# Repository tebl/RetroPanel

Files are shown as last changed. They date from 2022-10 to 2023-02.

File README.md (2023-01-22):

# RetroPanel
Having found a motherboard I really wanted to use, I found that obtaining an AT-case wasn't quite as easy as I had expected - at least none that met my demands for condition, price and availability anywhere near me. That's the short of it, see [Background](#2-background) for the full story. Anyway, my solution to my predicament was to simply use a slightly more modern ATX-case, but I wanted it to have all of the features available to even the earlies of computer generations available to me - that includes a working power switch, a turbo-switch and one of those awesome looking Mhz-displays. Add a clock and a temperature-sensor and it soon becomes apparent: such a thing, only had the potential to exist in my head.

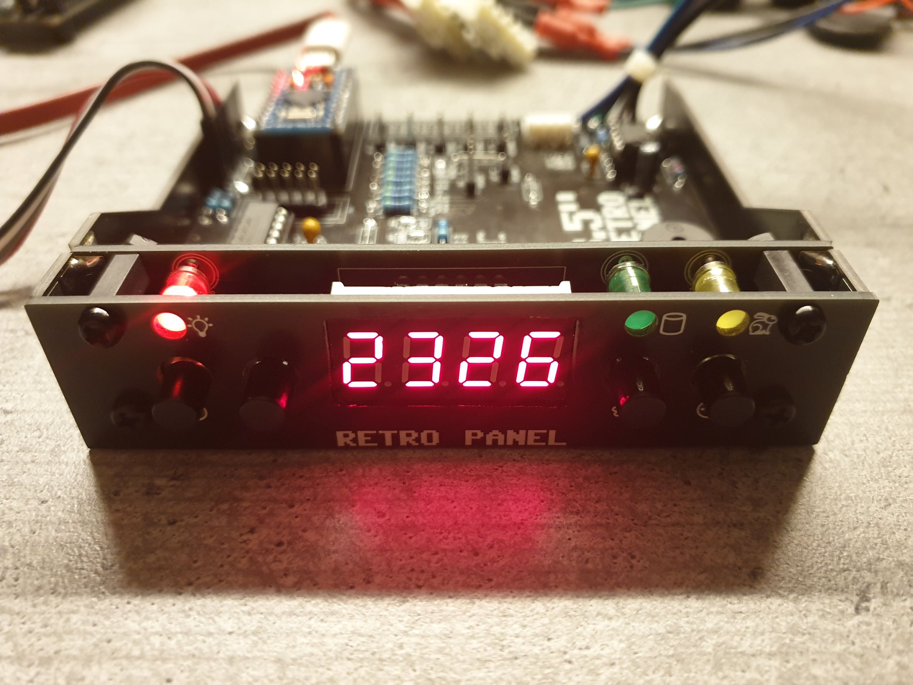
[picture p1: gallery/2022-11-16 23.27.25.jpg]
RetroPanel

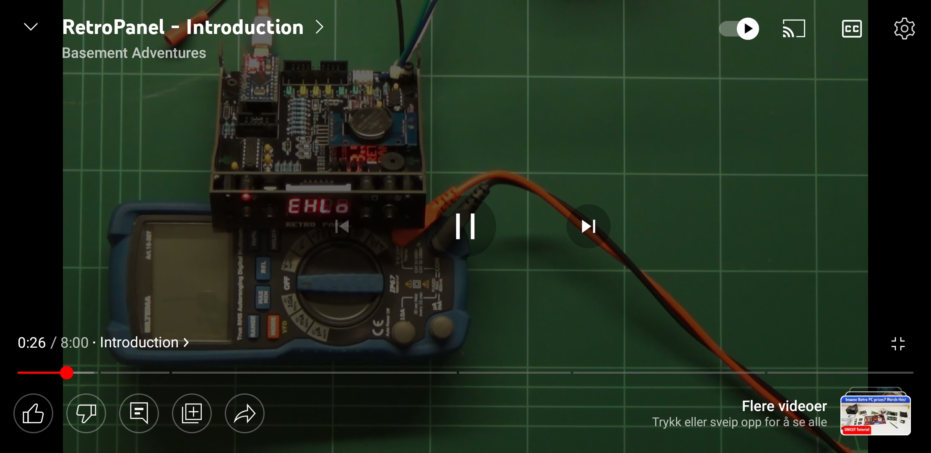
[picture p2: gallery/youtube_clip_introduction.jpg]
YouTube image (https://youtu.be/AMw6y9zLjqE)


So I made one.

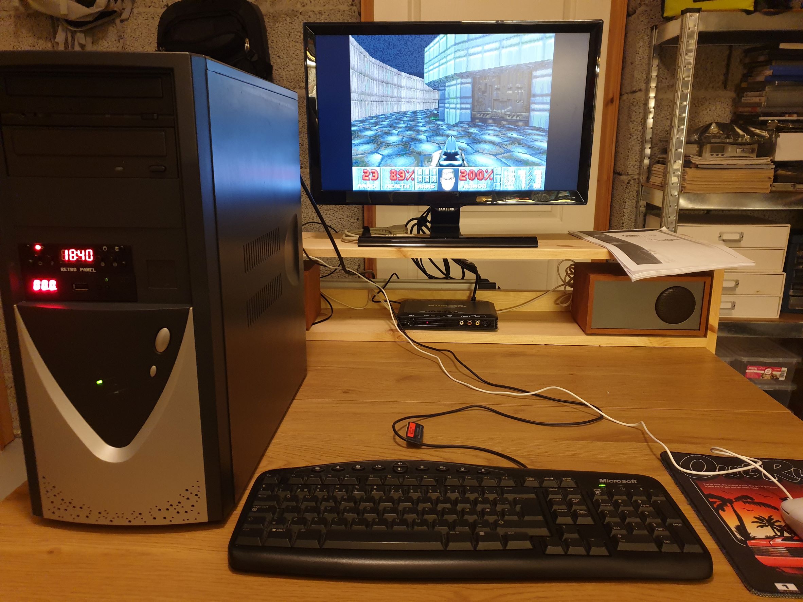
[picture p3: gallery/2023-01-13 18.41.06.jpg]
In action


The resulting computer isn't what I had originally intended to build, but I am quite happy with the results. There are better MBs, there are faster CPU options available and the graphics card will excite no other retro enthusiast other the one I grew into - however, it is exactly the *"right"* kind of slow for the games I remember. The *RetroPanel* was the missing piece to make all of that work, and with the wonders of *open-source* you should now have everything you need to build one as well.

- [1> Versions](#1-versions)
  - [1.1> RetroPanel](#11-retropanel)
- [2> Background](#2-background)
- [3> Resources](#3-resources)
- [4> Acknowledgements](#4-acknowledgements)

# 1> Versions
While there may only be one version of the RetroPanel for quite some time, but knowing myself and the fact that it has become a form factor that I really like - in time there will be more than one version of the RetroPanel. The differences will more than likely be in core functionality, not in terms of different faceplates that should already be catered for in the standard version.

| Module | Description |
| --- | --- |
| [RetroPanel](#11-retropanel) | Standard version

## 1.1> RetroPanel
RetroPanel

The standard version of the RetroPanel, envisioned to provide most features found on cases from even the earlies of computer generations - that includes a working power switch, a turbo-switch and one of those awesome looking Mhz-displays. With options for installing modules for adding a clock (RTC) to it as well as a temperature-sensor (BMP280).

The standard version is composed of the following set of PCBs, in the cases of alternative faceplates you would only need the one that is suitable for your needs. Follow the documentation links for specific information related to each of them, note that the documentation on building one of these units this is covered through the documentation for the main PCB ([RetroPanel Module](https://github.com/tebl/BulkyMIDI-32/tree/main/BulkyMIDI-32%20Module)).

| PCB | # Required | Description | Documentation | Order |
| --- | --- | --- | --- | --- |
| [RetroPanel Module](https://github.com/tebl/RetroPanel/tree/main/RetroPanel%20Module) | 1 | Main module | [Documentation](https://github.com/tebl/RetroPanel/blob/main/RetroPanel%20Module/README.md), [BOM](https://github.com/tebl/RetroPanel/blob/main/RetroPanel%20Module/README.md#3-bom) | PCBWay
| [RetroPanel Front](https://github.com/tebl/RetroPanel/tree/main/RetroPanel%20Front) | 1 | Front-facing board holding components | [Documentation](https://github.com/tebl/RetroPanel/blob/main/RetroPanel%20Front/README.md), [BOM](https://github.com/tebl/RetroPanel/blob/main/RetroPanel%20Front/README.md#3-bom) | PCBWay
| [RetroPanel Side](https://github.com/tebl/RetroPanel/tree/main/RetroPanel%20Side) | 2 | Design for the sides, you need two of these. | [Documentation](https://github.com/tebl/RetroPanel/blob/main/RetroPanel%20Side/README.md) | PCBWay
| [RetroPanel Faceplate (FP1)](https://github.com/tebl/RetroPanel/tree/main/faceplates/RetroPanel%20FP1) | 1 | Faceplate that goes on the very front of the module, this has provisions for all switches and LEDs | [Documentation](https://github.com/tebl/RetroPanel/tree/main/faceplates/RetroPanel%20FP1) | PCBWay

# 2> Background
Recently I had the glorious idea of rebuilding the first PC I bought, it was a low-budget option put together from a list of parts in the later parts of 1995. Due to sheer luck I still had some driver disks that came with it, so I knew that what I was looking for was a motherboard with the model number *P51437P4/FMB* as well as a *Cirrus Logic 5436* graphics card. Surprisingly expensive, no doubt because noone had felt like keeping the super-cheap hardware options in the first place - additionally it was an AT-motherboard with one of those clocks that you couldn't exchange the battery for.

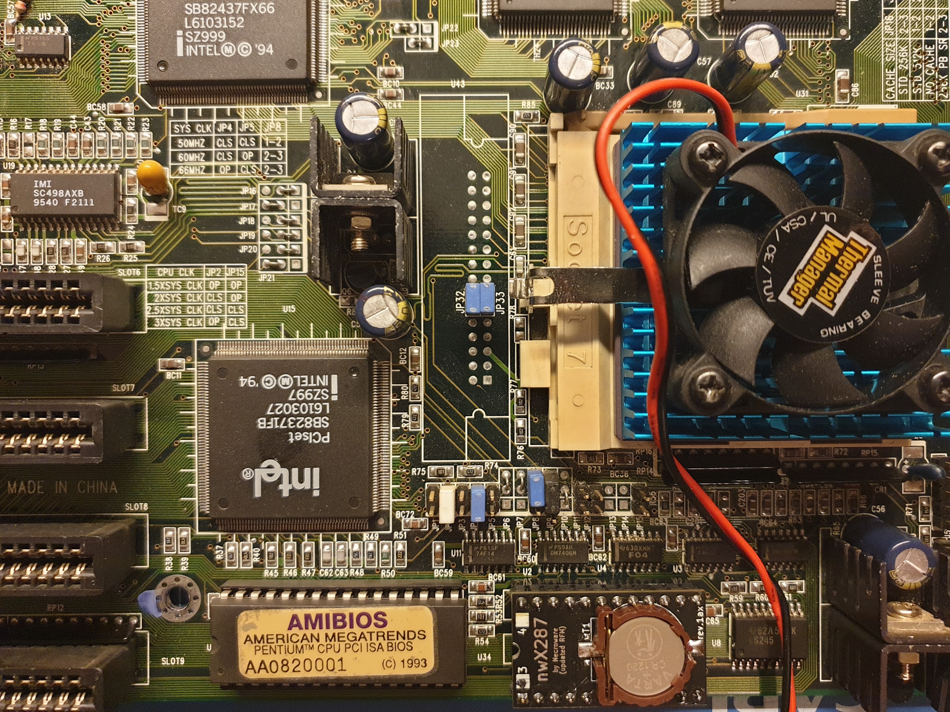
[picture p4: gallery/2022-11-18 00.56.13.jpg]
Old motherboard


Why does that matter? It doesn't, but the next thing does: I couldn't find an AT-case that wasn't either horribly mangled, situated around a collectors more beloved hardware or any combination of the two. Well, that's not completely true - I found and bought a case, but it was thrown from every moving postal truck from Poland all the way up to where I live - bringing us back to the first point on my little list.

RetroPanel in new case

No doubt having already listened in on my internal dialogue, YouTube gave me a viewing recommendation for a video from [philscomputerlab](https://www.youtube.com/@philscomputerlab) - [Building the 486 DX2 66 Retro Sleeper DOS PC](https://youtu.be/9bqqpuJ7M_I). What I liked with it was that he gave me a viable option by gently reminding me that ATX-cases are still plentiful, they're even easier to match the aesthetics of as most of the little bits are still being sold. His solution for powering was to use an ATX to AT-cable and using a simple toggle switch as a power switch, as is the common way of doing it.

There's just one thing I don't like about that, is that a part of the designs of the ATX PSUs is telling the power-on circuit on your motherboard not to instantly turn it on again once a short has been detected on one of its power rails. Have you tried shorting a 35A power supply? It'll scare the crap out of you, possibly vaporizing something in the process. Add a latching switch and it may keep cycling until you remove the power lead.

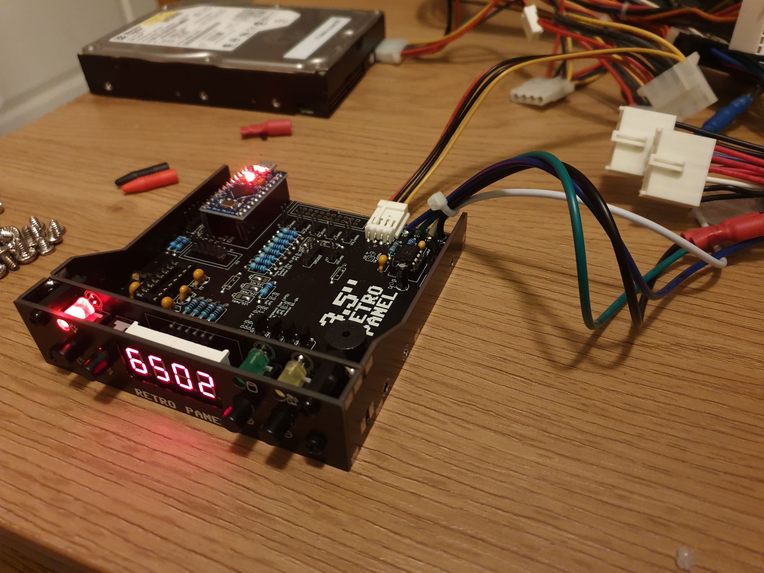
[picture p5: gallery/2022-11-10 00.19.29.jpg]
RetroPanel with PSU


I'm not saying that the RetroPanel in any way can be considered a safety precaution, because it haven't been tested enough to give you any other guarantee other than it having worked the one time I tried it. I still wouldn't keep a vintage computer powered without being in the room with it, but it gives me the peace of mind needed to turn my back long enough to fiddle with things such as this documentation.

# 3> Resources
The following resources where used as references when creating the RetroPanel, while they are in no particular order - you may find all of them interesting when looking for more information beyond what have been provided as part of this [GitHub-repository](https://github.com/tebl/RetroPanel). 

- [AT Power Pinout](http://www.hilmanind.com/pinouts/atpwr.htm)
- [ATX Power Pinout](https://www.etechnog.com/2022/03/atx-power-supply-pinout-diagram.html)
- [ATX Momentary Switch](https://www.instructables.com/Latching-Momentary-Switch-for-ATX-PSU-Conversion/)
- [PC power supply cables and connectors](http://www.playtool.com/pages/psuconnectors/connectors.html)
- [DIY POST Card](https://bbright.tripod.com/information/postcard.htm)
- [More POST Card information](https://www.minuszerodegrees.net/misc/post_cards.htm)

# 4> Acknowledgements
Everything comes from something, in particular when it comes to most of my electronics projects. I mainly build things I would like to own, often doing a respin to fit my own particular style and preferences. In many cases the hardest parts of the designs will already have been provided by people far more knowledgable than I. In particular the smart switch circuit, was adapted from [ATX Momentary Switch](https://www.instructables.com/Latching-Momentary-Switch-for-ATX-PSU-Conversion/).

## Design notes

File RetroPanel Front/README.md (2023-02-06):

# RetroPanel Front
This is a front-facing panel for controlling the *RetroPanel*, it holds all of the LEDs, switches as well as the 7-segment display associated with the RetroPanel itself. It mounts on the [RetroPanel Module](https://github.com/tebl/RetroPanel/tree/main/RetroPanel%20Module) using right-angle pin headers with slots cut into the PCBs to offer it some mechanical strength. The instructions for assembling one is mostly organized along with the main module, but the [BOM](#3-bom) included at the bottom of this document should be taken into account when ordering parts.

- [1> Building the device](#1-building-the-device)
  - [1.1> Soldering it together](#11-soldering-it-together)
- [2> Schematic](#2-schematic)
- [3> BOM](#3-bom)

# 1> Building the device
Building a device such as this assumes you have at least minor experience soldering things together, recommended is that you at the very least have access to a soldering station with adjustable temperature. If currently available, you should probably start with 60/40 rosin core solder as the lead-free alternatives tends to be a bit harder to work with.

With requirements for basic equipment sorted, we need to talk a bit about what you want to achieve while building this project. The reason I ask is that while you can build a *RetroPanel* with every feature available, it may not make sense for the computer it's going into. What I mean by that is that adding a turbo-switch wouldn't make sense unless your motherboard has a way of connecting it up. Have a read-through of the assembly instructions for the main [RetroPanel Module](https://github.com/tebl/RetroPanel/tree/main/RetroPanel%20Module) for a bit more details.

Now that you know what you want to build, we can get started on the most expensive step in any build process - shopping! So, head on over to the [BOM](#3-bom)-section for some information on what kind of components that you'll need. While I would have liked to give you specific part numbers for "reputable" electronic part suppliers, I can't afford to shop there so I usually make due with what I can find on sites such as ebay, AliExpress and any similar sites that sell cheap chinese components. The downside to this is that I can't link to a part directly and expect it to stay listed, so you'll need to consider the description listed as suggested search terms.

## 1.1> Soldering it together
The construction of this unit should be fairly straight-forward, just take your time in order to make sure everything goes into place - more or less straight. I usually recommend starting by having a good look at the PCBs, try to figure out where all of the listed components go and in which orientation they go in (all of this should be clearly marked on the silkscreen). The process of building it up should be covered in the assembly-video, click the picture below to jump directly to the relevant section.

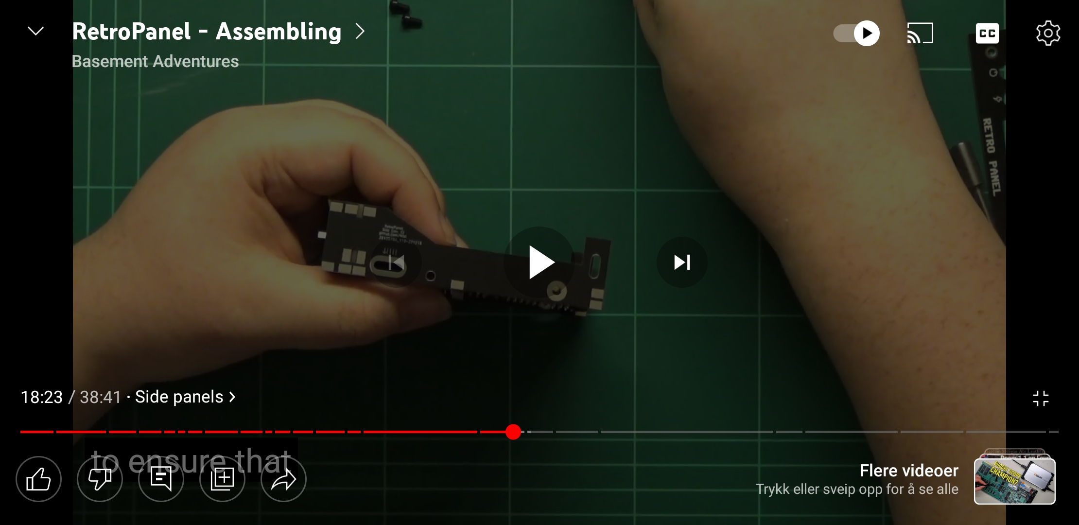
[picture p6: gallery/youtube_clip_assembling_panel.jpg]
YouTube image (https://www.youtube.com/watch?v=NcJ1v0hauTQ&t=729s)


The first component to go in, is a section of standard right-angle pin-headers - these are installed on the reverse of the PCB from what would otherwise be expected. The alignment must be done as neatly as you can, the easiest way of doing it is to soldering in a pin at each end - reheat and push the pin so that the plastic ends up sitting flush with the PCB. When satisfied with it, solder in the remaining pins.

Second is the switches that you need, these must have a black base at the bottom of them - this is important as the others will have a different pinout. Depending on the functionality that you need, some of these must be latching (*turbo*-switch in particular) while others must be non-latching (*reset* and the *tool*-button in particular). The power switch is a special case as it can be either, generally you want the latching variety when main unit is built **without** the smart power switch circuitry - in any other case you may prefer to use the switch already on your ATX-case.

The switches themselves has six pins and it may not be directly evident which of them is pin 1, so one common error is installing these upside down. Looking a bit closer at them you may observe that there is a square hole on the underside of them that is closer to one side, this is the square shown on the silkscreen. To avoid binding on the switches, take some care to get them sitting straight.

A faceplate is mounted on the top of the front, with 10mm hex standoffs between the two - in order to get the positioning of the LEDs correct, you should add them to the outside corners and fix them in place using M3 nuts.

Depending on what features you wanted to use it with, you may require up to three standard 5mm LEDs - these should be roughly put into place in their holes without soldering them into place. Longer pin of the LED goes into the round-shaped pad on the PCB. Temporarily adding the faceplate into place on top, allow the LEDs to fall into the cutouts made for them - only then, do you solder them into their place.

The 7-segment display can be added to the module in a couple of ways, at least two ways that I've though of so far:
- The first is to solder female machined header pins to the PCB, then insert a display with shortened pins into the header pins. This does include the joys of dealing with female machined pins such as those usually found on sockets, but at the advantage of being able to easily change out or replace the display later.
- The other is to align the display with the inside edge of the faceplate, that way the pins of the display should almost poke through to the back of the PCB. Filling the holes with a controlled amount of solder should still allow a good connection, just allow it to flow completely through to the front edge of it. 

In either case, if you cant seem to get the display to fit through the cutout on the faceplate you may need to shave a bit off the inside edges with a sharp disposable blade. The reason for this is that PCB fabrication tend to be less exact when dealing with inside edges such as these. Additionally you may find that it also becomes easier once the plastic film on the front of the displays have either been removed, or slightly trimmed down to fit the outline better (I think it's supposed to be removed, but I don't know for sure).

That should be all there is to it when it comes to assembling the front panel, for actually installing it on the main module - jump on over to the main assembly [documentation](https://github.com/tebl/RetroPanel/blob/main/RetroPanel%20Module/README.md#12-adding-the-front).

# 2> Schematic
The supplied KiCad files should be sufficient as both a schematic and as a  starting point for ordering PCBs (basically you could just zip the contents of the export folder and upload that on a fabrication site), the schematic is also available in [PDF-format](https://github.com/tebl/RetroPanel/tree/main/documentation/schematic) and this is what you'll need to print and work your way through this things don't work as expected after assembly.

# 3> BOM
Most parts should be easy to get a hold of from your favourite local electronic component shop, but given that I don't have access to such shops where I live so everything was based on whatever I could get cheapest from eBay/AliExpress (free shipping, but plan on waiting 3-4 weeks for delivery). Normally I would specify the number of components in parenthesis that can be considered optional for features beyond the more basic functionality, but at this point you should already have a concise idea of what you're going to need.

| Reference | Item | Count | Order  |
| --- | --- | ----- | --- |
| Panel PCB | Fabricate using Gerber files | 1 | PCBWay
| D1-D3 | 5mm LEDs, preferably frosted or solid colour (not the bright clear ones) | 3 |
| J1 | Breakable right-angle pin headers | 1 |
| SW1 | 6pin 8.5mm x 8.5mm latching switch | 1 |
| SW2 *1 | 6pin 8.5mm x 8.5mm latching **OR** non-latching switch | 1 |
| SW3,SW4 | 6pin 8.5mm x 8.5mm non-latching switch | 2 |
| Mounting *2 | Nylon M3 hex standoffs 10mm (M-F) | 4 |
| Mounting *2 | Nylon M3x6mm nylon screws | 4 |
| Mounting *2 | Nylon M3x6mm nylon nuts | 4 |

1) As mentioned in the documentation, the power switch can be a a non-latching (also known as a momentary switch) when used with the smart power circuitry on the main module. When assembling a module without this functionality, you will need a latching switch here in order to turn on an ATX-PSU when used with an AT-motherboard.
2) These are available in the form of kits usually advertised *M3 nylon standoff kit* which should contain most of what you'd need. I do however recommend that you pick up extra M-F standoffs of lengths 8mm and 20mm, as quite a lot of them will be used when building more than one module.

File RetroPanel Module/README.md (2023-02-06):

# RetroPanel Module
The standard version of the RetroPanel consists of several separate PCB designs, five in total with two of these being the duplicated side panels. The piece of documentation you're currently looking at covers the main module as well as the overall build details, but take note that many of the other boards such as the [RetroPanel Front](https://github.com/tebl/RetroPanel/tree/main/RetroPanel%20Front) also comes with its own set of documenentation - so make sure that you browse around to get the full picture (especially when ordering parts). If you don't have any idea what all this is about, have a read through the [main documentation](https://github.com/tebl/RetroPanel) first.

Completed unit
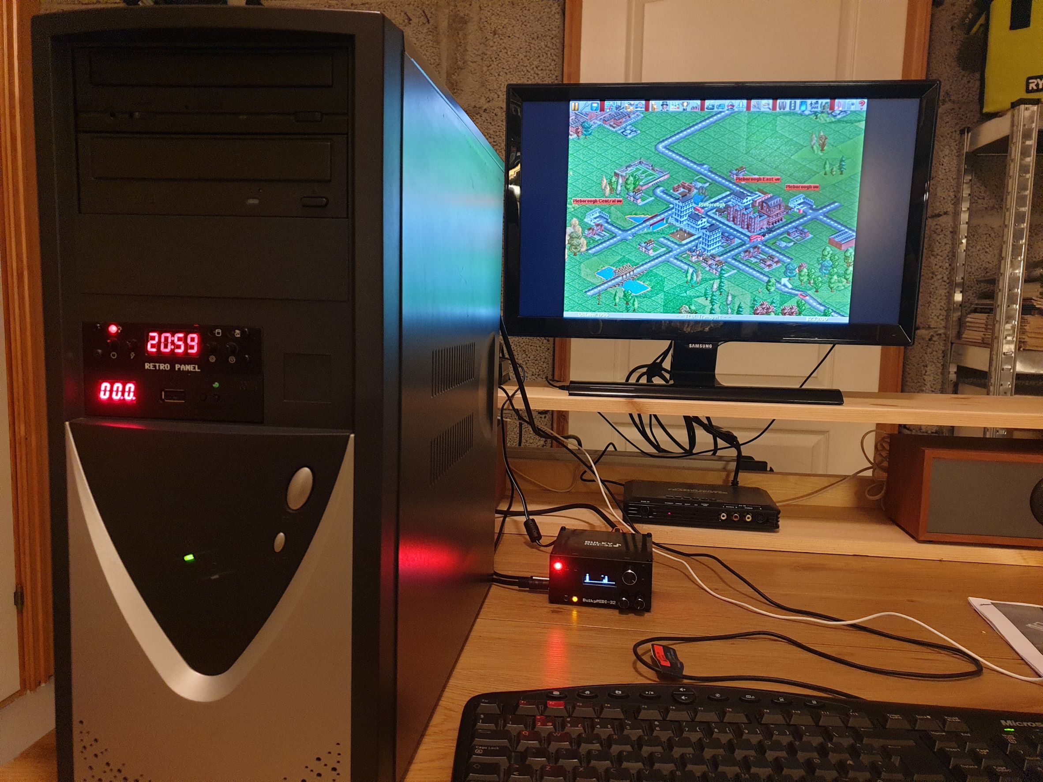
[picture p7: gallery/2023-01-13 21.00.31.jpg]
Installed in a system


- [1> Building the device](#1-building-the-device)
  - [1.1> Soldering it together](#11-soldering-it-together)
  - [1.2> Adding the front](#12-adding-the-front)
  - [1.3> Adding side panels](#13-adding-side-panels)
  - [1.4> Adding the cables](#14-adding-the-cables)
  - [1.5> Finishing touches](#15-finishing-touches)
- [2> Schematic](#2-schematic)
- [3> BOM](#3-bom)

# 1> Building the device
Building a device such as this assumes you have at least minor experience soldering things together, recommended is that you at the very least have access to a soldering station with adjustable temperature. If currently available, you should probably start with 60/40 rosin core solder as the lead-free alternatives tends to be a bit harder to work with.

With requirements for basic equipment sorted, we need to talk a bit about what you want to achieve while building this project. The reason I ask is that while you'll be able to find something for anyones taste in the project, at least provided that they enjoy building with vintage computer hardware. The following features can more or less be built separately:
- Panel for switches and LEDs missing from modern case
- Smart power switch
- One of the following:
    - External display for common ISA/PCI diagnostic cards
    - Arduino-driven display for use as a Mhz-display if needed, additionally the following features can be added to it:
      - Clock
      - Temperature display
      - RS-232 functionality for displaying information on the display, accessible through a simple serial interface.

YouTube image (https://youtu.be/AMw6y9zLjqE)

Now that you know what you want to build, we can get started on the most expensive step in any build process - shopping! So, head on over to the [BOM](#3-bom)-section for some information on what kind of components that you'll need.

**NB!** While I would have liked to give you specific part numbers for "reputable" electronic part suppliers, I can't afford to shop there so I usually make due with what can be found on sites such as ebay, AliExpress and other sites that sell *cheap* chinese components. The downside to this is that I can't link to a part directly and expect it to stay listed, so you'll need to consider the description listed as mere *suggested search terms*.

## 1.1> Soldering it together
The construction of this unit should be fairly straight-forward, just take your time in order to make sure everything goes into place - more or less straight. I usually recommend starting by having a good look at the PCBs, try to figure out where all of the listed components go and in which orientation they go in (all of this should be clearly marked on the silkscreen).

While I would have liked to take every precaution and cover every possible combination of features, but for the purpose of keeping this document somewhat coherent - from this point on I'll mostly just assume that you're going to install every feature available. If you prefer something a little more visual, I've also taken the time to create a video in order to cover most of this - just click the image below.

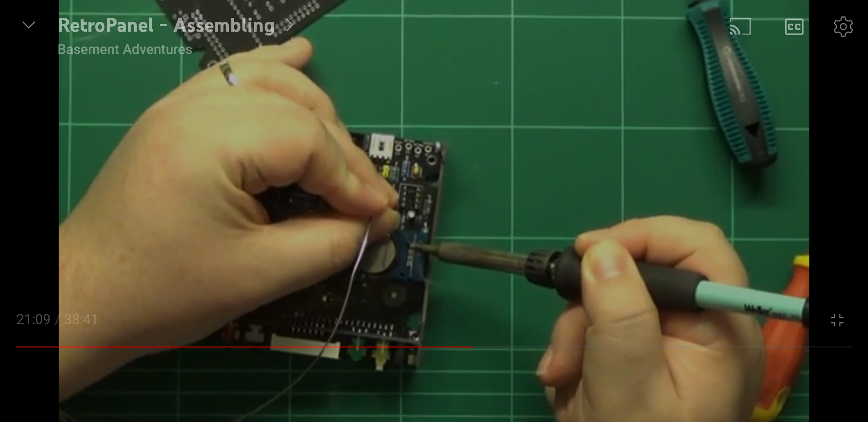
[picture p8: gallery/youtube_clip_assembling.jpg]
YouTube image (https://youtu.be/NcJ1v0hauTQ)


If you only want parts of it, follow along on the schematic so that you know where each part are used. If you only wanted to use this as an external display for a diagnostic card, you'll generally only install the *J9*-connector for it and almost no other component. It can easily be combined with the smart switch, if you need that - it is separate from all of the Arduino-related circuitry.

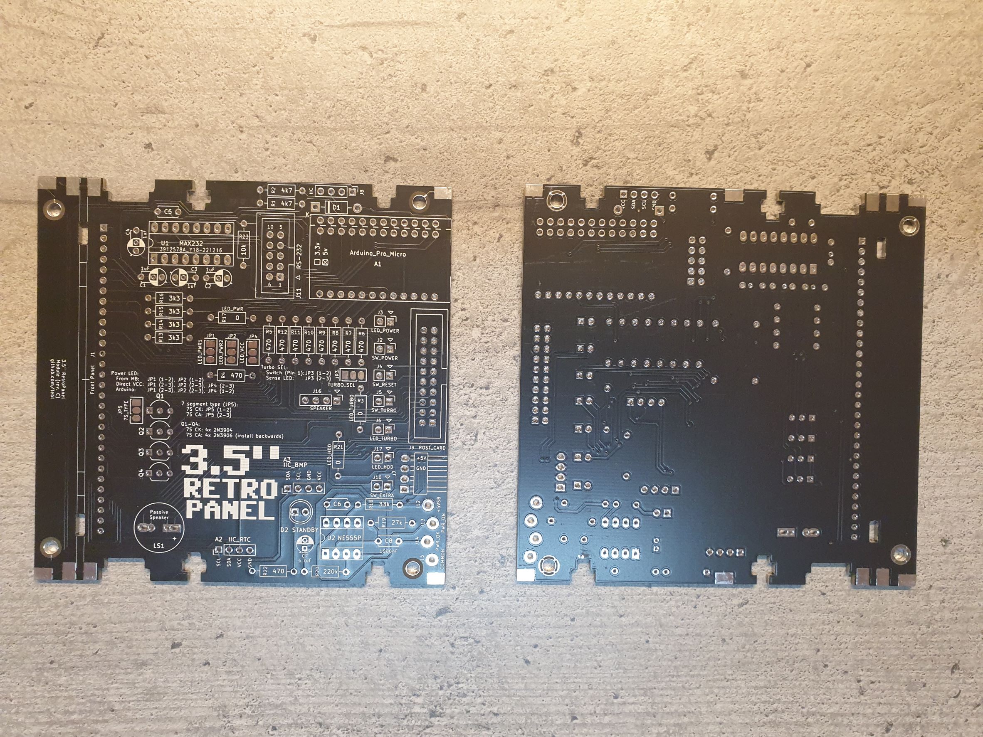
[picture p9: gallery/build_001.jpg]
Build 001


In order to assure that the solder-jumpers are easy to set, it's a good idea to get those out of the way as the first we do - most of the information should be visible be in some form on your PCB (pin 1 out the 3 encountered will be square, with the others having a rounded shape). For example, the one marked *JP5* needs to be set according to the type of 7-segment display you've ordered, set it to *1-2* for CK (*Common Kathode*) or *2-3* for CA (*Common Anode*). *JP3* should be set to *1-2*. The safe choice for *JP1*, *JP2* and *JP4* is *2-3*, *2-3*, *2-3* though it won't be crucial unless you're building a cut-down version of the design.

When it comes to the components themselves, I will usually try to install them in the order according to their physical size. Doing it this way means you'll have an easier time keeping everything from looking crooked, but this is your board, your build and you want it perfect - don't you? If you said no, then go sit in the corner, because I worked hard on creating this for you.

I usually start by soldering in all of the resistors, ensuring that we're using the correct values in each of the positions. In some of the positions you will encounter the value specified as "0", or zero - these can be replaced with small pieces of wire. The reason that these exist is that a computer motherboard will likely expect an LED from that period in time, while you might be tempted to install something quite more modern in their place. The ones I'm referring to are usually sold as *"bright"* or *"clear"* LEDs, their efficiency is far higher than their old counterparts and for that reason you can install suitable resistors in these places to bring their brightness down (some may even require a value of 1k and above). All of that may require you to find and read the relevant datasheet, then do the needed math to find a suitable value. Or just do what I usually do: use the old style of coloured LEDs.

**NB!** Resistor *R23* directly next to the MAX232 is part of the MAX232-circuit, but you need to install it regardless of not wanting RS-232. The serial interface may have spurious issues working without it, so either add it - or - alternatively ensure that you disable the interface in the Arduino sketch before uploading it (*settings.h*).

The single diode marked *1n5819* is next, paying particular attention that the silver band of the component need to match that of the markings on the PCB. The purpose of it is to ensure that if you were to connect the USB-lead from the *Arduino Pro Micro* up to your modern laptop with the module installed in a different computer, this ensures that the Arduino won't attempt and more likely burn out while trying to power up the vintage PC. Meaning in theory you could replace it with a wire as can be shown in some of the gallery images, but this shouldn't be part of any kind of recommendation.

Sockets should be installed for the two ICs needed for the complete unit - you could probably manage without them if you know that you're using known good parts. However, they're cheap and you could probably afford to be quite so *cheap*!  I recommend tacking opposing corners into place, then reheat and push flush against the board before soldering the remaining pins.

Next to follow will be the non-polarized capacitors, the kind I use are mostly monolithic capacitors - mostly because I prefer their uniform look over the standard ceramic capacitors. Whatever the difference is, I have no idea beyond that so far they have worked as expected. The area around *U1*, the MAX232 chip, will have some rather peculiar-looking footprints - the reason for this is that the requirements are different for different versions of the chip - the slightly more expensive chip in the form of the MAX232**A** will want the regular 100nF capacitors and you should therefore add those now. The slightly cheaper is usually option will have something else as their first letter, usually a "**C**" though that stands for something else in the comparison - generally these will require polarized electrolytic capacitors added later. 

**NB!** Most electrolytic capacitors have a 100nF value (usually marked *104* directly on it), the ones that require a different value specifically have that printed on the board. Specifically I'm talking about *C8*, it is part of the smart switch and needs a value of 1000nF (this should me marked *105*).

Moving on we'll look at connectors, of which there are only two that we need to think about. As the Arduino is mutually exclusive with using the display with a diagnostic card, you'd only install *J9* when no Arduino is installed (I put my Arduino on a socket so that I can decide later). *J11* is used with RS-232, install if needed and intended. I prefer using IDC-connectors as those are properly keyed, but if you don't have any of the correct size available you may substitute them with regular straight pin-headers.

Speaking of capacitors, we'll just go ahead and install the polarized ones as well. If you opted for the cheaper variant of the MAX232-chip (the one not marked MAX232 and **A** as its first letter), there should be four of them close to this chip. Ideally you've not yet installed a bunch of non-polarized capacitors here already, if you have - then you either need to get the better chip or remove them. As polarized as they are, we need to ensure that these are always installed the right way around - the stripe on the side of the capacitor denotes the negative side of it, this should match the filled in (white) area on the footprint. When in doubt, the longer pin goes into the other hole - the one marked with an extremely tiny "+" next to it.

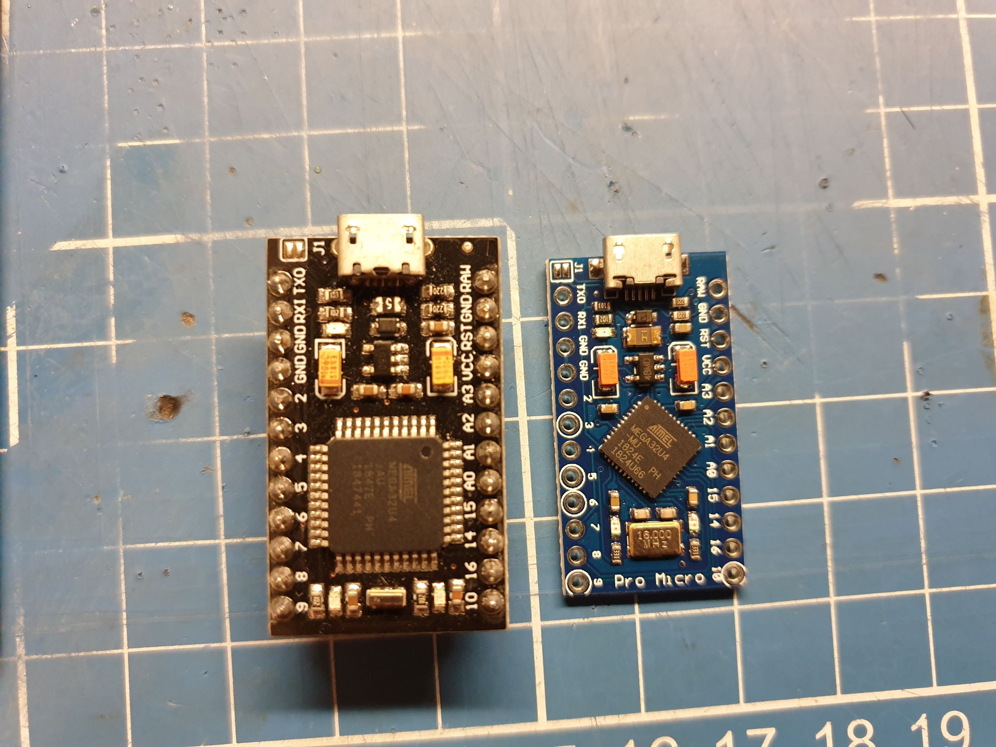
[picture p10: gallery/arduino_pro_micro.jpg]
Arduino Pro Micro variants


I usually tend to solder female pin-headers to modules that I want to remove later, such as the *Arduino Pro Micro*. The *Pro Micro* unfortunately comes in a slightly wider, and a more narrow version depending on what you're used to - this is the reason for the double set of pins on one side. When using female pin-headers on the module itself, this does not matter much. However when we instead intend to solder it straight to the board, you need to make sure to solder in the version that matches your board specifically. *A2* and *A3* we give the same treatment, they're for the *clock* and *temperature* modules that we have the option of adding.

While we're already dealing with pin-headers, just go ahead and all of those that we intend to a signal from the computers motherboard at some point. That should be all of those remaining, primarily the column directly under the *Arduino Pro Micro*. Personally I tend to use different coloured pin headers for those that will connect up to a LED compared to those going to switches, mostly so that I don't have to think so hard about what's going where. They'll never go in straight the first time, so just solder in the first pin - that way you can adjust them before soldering it all the way. You will burn your fingers doing at least one of them, that's the natural law of soldering short pin-header segments. 

## 1.2> Adding the front
Soldering together the front panel will be covered as part of its [documentation](https://github.com/tebl/RetroPanel/blob/main/RetroPanel%20Front/README.md#11-soldering-it-together), including a separate [BOM](https://github.com/tebl/RetroPanel/blob/main/RetroPanel%20Front/README.md#3-bom). Remembering that we earlier set some jumpers according to the display that was used, also - we remembered to use a latching power switch if we had decided against installing the smart switch circuit (momentary switch when it is used). As this needs to be added correctly, consider checking out the [assembly](https://youtu.be/NcJ1v0hauTQ?t=978)-video to see this chapter in action first.

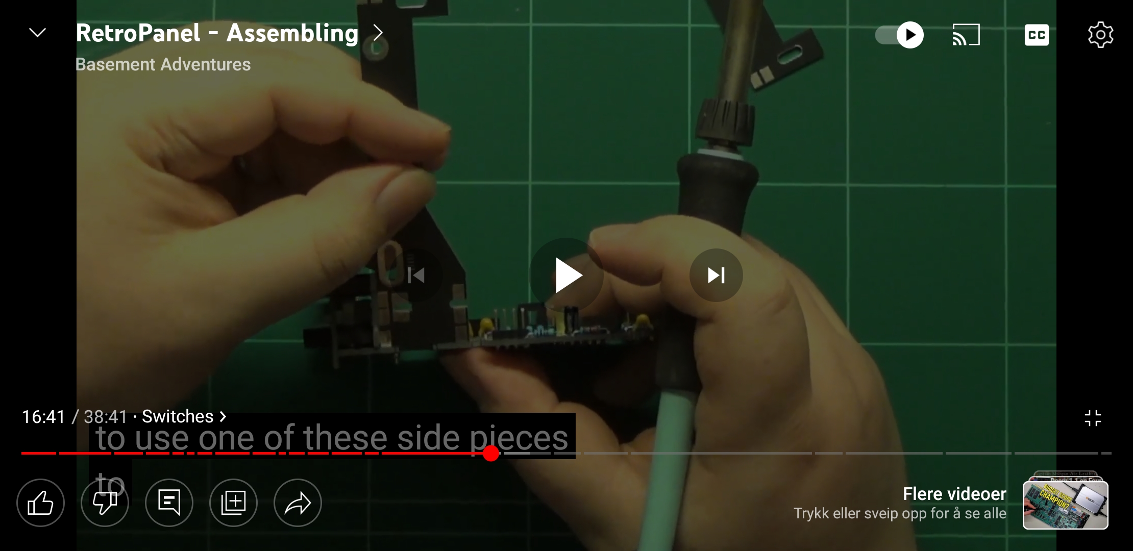
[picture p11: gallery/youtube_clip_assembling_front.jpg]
YouTube image (https://youtu.be/NcJ1v0hauTQ?t=978)


With a completed front panel in front of you, it should easily slot into the main PCB - some resistance due to slightly crooked right-angle pin can be expected, but it shouldn't be an issue if you did your job well. When soldering it to the main board, just start with the opposing corners and ensure that it is at an almost perfect **90 degree angle**. While that sounds like something that'd be hard to do, you can easily use the sharp angle on your two side panels to check.

Do this for **both** of the outer edges!

When satisfied, solder the remaining pins. Using your most solid wire clippers to trim the excess of the pin headers from the underside.

**WARNING!** Do **NOT** use your standard side cutters as this will either dull them - OR - have them break in a spectacular fashion. By "*spectacular*" I mean sharp shrapnel, suddenly flying past your head. Failing that, at least use some sort of eye protection. 

## 1.3> Adding side panels
Start by adding some screws to each of the four corners of the PCB, with the nut on the underside - the screw should be loose, and **NOT** poke through the bottom of the nuts. You may need to temporarily remove the hex standoffs from the front panel in order to access these.

YouTube image (https://youtu.be/NcJ1v0hauTQ?t=1027)

On each of the outside edges there is a cutout for another M3 nylon nut, with two of the flat edges inserted so that it'll sit flush with interior edges of the PCB (use a small set of pliers, if you're having a rough time of it with large fingers). Rougly put one of the side panels into place, inserting a short M3 screw from the outside into this middle groove - it should grab onto the nut and pull the side panel firmly into place. You may need to hold a finger on the underside to keep the nut from falling through, it's a bit fiddly though you'll soon get the hang of it. Do the same for the other side.

Put the whole construction back on a clean work surface, ideally one that isn't warped in any way. Push it gently down so that both sides as well as main PCB, sit as straight as they can. The sides will rotate slightly into the correct place, the main PCB should level itself with the nuts at the bottom ensuring that the distance becomes correct in relation to eachother (this was why the screws used here shouldn't poke through them). If unsure about any angles, use a spare PCB as a level as done earlier.

**NB!** PCBs do tend to warp slightly when heated, this is why you're gently pushing and prodding things here and there to get things right. If something straight up feels like it's scraping against the table, there may be something on the underside that have been left poking to far through. Cut it down to a reasonable height and try re-adjusting the whole thing again.

Notice that on the inside of the module, there are large SMD-pads that'll align in the intersection between the various boards. Working along the outside edges, add a lot of solder to first one of the pads and then the one near it - moving between them to distribute heat between the two, you should be able to permanently stick the two together using this now rather large blob of solder. Intentionally shorting them together, you've now welded the corner together.

Keep working until you're sure no part of it will ever come loose again, remember that this also includes the parts where the side panels interlock with the front panel. When satisfied, turn the whole thing over and keep doing there the same as well.

Remove the nuts and screws from the four corners, use them to re-attach the front panel with its faceplate again. Sorry about the back and forth, but I find that having all the pieces available at the right helps to get things right the first time.

## 1.4> Adding the cables
The RS-232 cable isn't what I was aiming at, at least at this point in the guide beyond a few short hints. It was designed to simply be a 10-wire ribbon cable, with a 2x5 IDC-connector on one side and a female DE-9 (often mistakenly described as a DB-9) on the other. Usually I a bunch of cables with 2x5 IDC-connectors on each end, then cut one end off before adding a DE-9 IDC to that end (pin 1 matched to pin 1). Given that serial cables can have all sorts of weird wiring, it's easier this way as you can control what you end up getting.

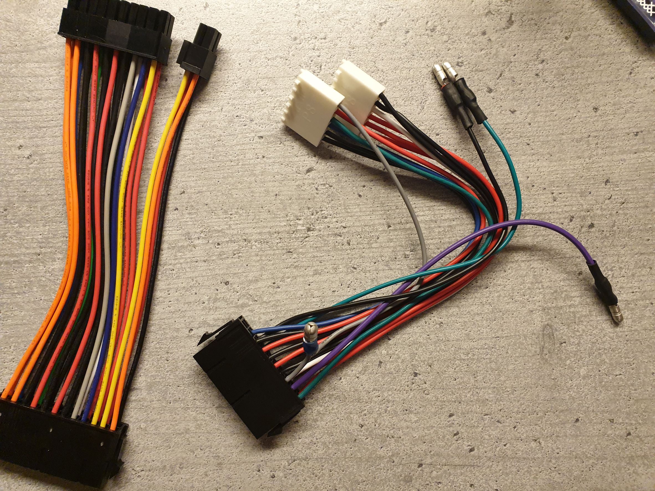
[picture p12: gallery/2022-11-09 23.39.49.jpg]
ATX to AT cables


Over to the part you were probably wondering about, the one belonging to the smart switch in combination with cheap ATX to AT cables - normally requiring four cables:
- a *black* ground
- a *normally* green *PS_ON*
- a *normally* purple *5v Standby*
- a *normally* *gray* *PS_OK*.

That's a lot of *"normally"* to use in a description, the reason is that whoever produced the cable might not have followed the standard and just ensured that the cables went in the expected places. When in doubt, refer to this [pinout](https://www.etechnog.com/2022/03/atx-power-supply-pinout-diagram.html) so that you know what the positions of the cables you're working with. At first that might not make sense when staring at it, but once you realize that the three orange wires at the top are missing, leaving a recognizable shape in the connector - the rest should fall into place.

You should already have the *black* and *green* cables hanging off to the side on your cable, using an ATX-extension cable as a source of mostly suitable wire - you should take the oppurtunity to get rid of the spade-connector and extend these cables. The *purple* one is missing entirely so this one we need to salvage from the extension cable, a couple of needles inserted to the sides at the front should eventually release the cable from its current use - ideally without the destroying the little hooks, salvage some other similar wire and extend it as with the others. The *gray* one is also going to the white AT power-connectors, cut it and add an additional new cable going through it - we're splitting it two (meaning it should still go to the  PCs *motherboard* in addition to the *RetroPanel*).

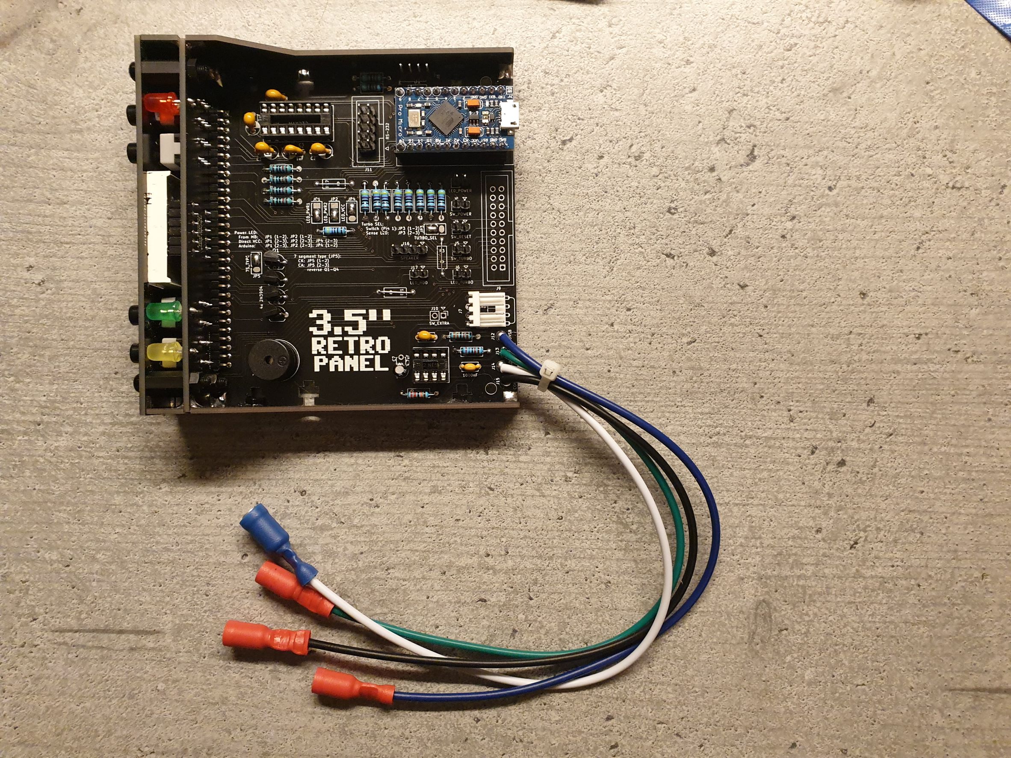
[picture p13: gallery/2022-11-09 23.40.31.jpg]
Soldered to the board


Solder the cables to the board, going from the outside edge these should be *black*, *gray*, *green* and then finally the *purple* one (I didn't actually have this colour cable, so it is blue in the picture). In order to ensure that these do not easily detach from the board, I usually add the shortes F-F standoff I have available to the hole next to them - adding a screw to the underside to hold it in place. A second screw is added at the top, but loosely. Adding a zip-tie around the cables and this screw, I can then tighten the screw/zip-tie to ensure that the cable harness can withstand significantly more handling before coming undone.

**WARNING!** Remember to trim the wires on the underside - we don't want these wires to accidentally short against whatever is directly beneath the module when installed in a PC. It should provide enough of a space that this isn't a problem, just don't get sloppy with it.

## 1.5> Finishing touches
Start by inserting the chips into their sockets if you have not already done so, enshure that you get the indent marking pin 1 facing towards the front panel. New chips will have their pins splayed slightly and could be hard to get into a socket, if you don't have a DIP pin-straightener then just push one side flat against the work surface. You will need to have some way of screwing it into your computer case, by far the easiest way of doing that is to superglue M3 nuts into the groove cut into the main PCB, to get the positioning correct: Put a screw through the PCB from the outside and into the nut, then use superglue to glue the nut into place. Remove the screw halfway through curing so that you don't accidentally glue that in as well. Depending on the type of case, you might not need any screws towards the front. The PCB has wide cutouts to accomodate different cases, and you may need to test that it sits flush against the front before committing to a placement - the purpose is to allow the design to be slightly moved forwards or backwards.

Unless one had been provided to you by a kit-maker, you will more than likely not have the correct firmware installed on your *Arduino Pro Micro*. The code you need can be found as part of this repository on the URL [software/arduino/RetroPanel](https://github.com/tebl/RetroPanel/tree/main/software/arduino/RetroPanel), and you will need to download a complete copy of this repository. This is accomplished by using the green button on the [main page](https://github.com/tebl/RetroPanel) of the GitHub-repository and then hitting *Download ZIP*.

Additionally, you will need to install a couple of libraries in order for the code to actually compile. The [README](https://github.com/tebl/RetroPanel/blob/main/software/arduino/RetroPanel/README.md) contains links to all of these, the easiest way of obtaining a copy of them will be to install them via your Arduino development environment. 

For Arduino Studio, open the sketch and then select the board that you have (Arduino Nano of some kind). Install the two libraries from *Tools* --> *Manage libraries...* - to search for and install the missing libraries. Check that the code now compiles, select the serial port corresponding to your module and upload the sketch.

PlatformIO should handle dependencies somewhat automatically, though I find that in practice we need to run a command for it to happen. Open up a new PlatformIO Terminal (not PowerShell, it's probably the last icon on your bottom toolbar), then run the command *"pio pkg install"*, and it should download and install the latest version of the libraries needed. Ensure that the environment selected on the bottom toolbar corresponds to the board you are using, you may need to edit *platformio.ini* if neither of the combinations is correct for you. Compile and upload the code.

Using a serial terminal connected to the *Arduino Pro Micro*, you may configure the device according to your preferences. Among the more helpful commands is the *help*-command, as that should tell you most that is needed. Settings need to be explicitly saved using the *save*-command to store them permanently to the onboard EEPROM, this helps when you're unfamiliar with the interface. For more detailed information as well as serving as a reference, see [Serial Interface](https://github.com/tebl/RetroPanel/blob/main/documentation/serial_interface.md).

# 2> Schematic
The supplied KiCad files should be sufficient as both a schematic and as a  starting point for ordering PCBs (basically you could just zip the contents of the export folder and upload that on a fabrication site), the schematic is also available in [PDF-format](https://github.com/tebl/RetroPanel/tree/main/documentation/schematic) and this is what you'll need to print and work your way through this things don't work as expected after assembly.

# 3> BOM
Most parts should be easy to get a hold of from your favourite local electronic component shop, but given that I don't have access to such shops where I live so everything was based on whatever I could get cheapest from eBay/AliExpress (free shipping, but plan on waiting 3-4 weeks for delivery). Components in parenthesis can be considered optional for features beyond the more basic functionality, but where's the fun in that? You deserve the complete package.

I've made an attempt at including everything, and possibly the feature it is associated with. Note that for this reason, one identical part will be listed several times and you need to add the counts to get the total number of parts. Remember that the front panel also has its BOM-section. I recommend picking up extra sets of pin-headers if you don't already have those available, in particular the female variety if you intend for the modules to be removable.

| Reference | Feature | Item | Count | Order  |
| --- | --- | --- | ----- | --- |
| RetroPanel Module | | Fabricate using Gerber files | 1 | PCBWay
| [RetroPanel Front](https://github.com/tebl/RetroPanel/tree/main/RetroPanel%20Front) | | Fabricate using Gerber files | 1 | PCBWay
| [RetroPanel Side](https://github.com/tebl/RetroPanel/tree/main/RetroPanel%20Side) | | Fabricate using Gerber files | 2 | PCBWay
| [RetroPanel Faceplate (FP1)](https://github.com/tebl/RetroPanel/tree/main/faceplates/RetroPanel%20FP1) *1 | | Fabricate using Gerber files | 1 | PCBWay
| A1 | Arduino features | Arduino Pro Micro (5v) | 1 |
| A2 | Arduino features | DS3231-module, I2C RTC - usually marked ZS-042 | (1)|
| A3 | Arduino features | BMP280 **5V**, I2C temperature sensor | (1)|
| C1-C4 *2 | RS-232 | 100nF ceramic capacitor (5mm) or 1uF electrolytic capacitor (D4mm, 2mm) | 1 |
| C5 | RS-232 | 100nF ceramic capacitor (5mm) | 1 |
| C6 | Smart Power | 100nF ceramic capacitor (5mm) | 1 |
| C7 | Smart Power | 4.7uF electrolytic capacitor (2mm pin spacing) | 1 |
| C8 | Smart Power | 1000nF ceramic capacitor (5mm) | 1 |
| D1 | | 1N5819 Schottky diode (DO-41) | 1 |
| D2 | Smart Power | 5mm LED | (1)|
| J2-J6,J10,J17 | | 1x2 pin, straight header pins | 7 |
| J7 | | JVC Mini 4P Connector Floppy Power Supply Jack 2.54mm | 1 |
| J8 | Arduino features | 1x4 pin straight header pins | (1)|
| J9 *3 | External POST-display | 2x10 pin straight header pins, preferably 2x10 IDC socket | (1)|
| J11 | RS-232 | 2x5 pin straight header pins, preferably 2x5 IDC socket | 1 |
| J16 | | 1x4 pin straight header pins | (1)|
| LS1 | | Small passive speaker, fits pin spacing from 3.8mm  up to 8.7mm | (1)|
| Q1-Q4 *5 | Arduino features | 2N3904 (TO-92), alternatively 2N3906 (TO-92) | 4 |
| R1,R2 | Optional I2C modules  | 4k7 (4700) ohm resistor | (2)|
| R3,R17,R21 | | Used to offset resistance needed by LEDs, use wire if not needed  | (3)|
| R4 | | 470 ohm resistor | 1 |
| R5-R12 | Arduino features | 470 ohm resistor | 8 |
| R13-R16 | Arduino features | 3k3 (3300) ohm resistor | 4 |
| R18 | Smart Power | 33k ohm resistor | 1 |
| R19 | Smart Power | 27k ohm resistor | 1 |
| R20 | Smart Power | 220k ohm resistor | 1 |
| R22 | Smart Power | 470 ohm resistor | (1)|
| R23 | | 10k ohm resistor | 1 |
| U1 | RS-232 | MAX232 (DIP-16), preferably MAX232**A** | 1 |
| U2 | Smart Power | NE555 timer (DIP-8) | 1 |
| ATX to AT cable | Smart Power | Cheap cables sold for ATX to AT PSU conversion | 1 |
| ATX extension cable | Smart Power | Cheap cable, used for spare parts | 1 |
| Mounting | | Nylon M3x6mm hex standoff (F-F)) 									| 8 |
| Mounting | | Nylon M3x6mm nylon screws | 8 |
| Mounting | | Nylon M3x6mm nylon nuts | 6 |

1) Various [faceplates](https://github.com/tebl/RetroPanel/tree/main/faceplates) will be made available as part of this project, the one linked here is simply the one with provisions for all features.
2) As mentioned in the build instructions, the value of these depend on the type of MAX232-chip used. The MAX232**A** requires 100nF capacitors, the others require 1uF electrolytic capacitors installed here (these should have a maximum diameter of 4mm, with a pin spacing of 2mm).
3) The usage of the module as an external display for common ISA/PCI diagnostic cards (also known as POST cards), requires that the 7-segment display on the front is of the Common Anode variety. This option can't be combined with the Arduiono.
4) These are used in various places of the project, these are available in the form of kits usually advertised *M3 nylon standoff kit* which should contain most of what you'd need.
5) The type of transistor depends on type of display to install on front panel, 2n3904 when used with CK (Common Kathode) displays. 2n3906 installed backwards when used with CA (Common Anode) displays.

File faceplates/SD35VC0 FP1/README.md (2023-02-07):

# SD35VC0 (FP1)
A faceplate designed to be installed onto the RetroPanel SD35VC0 [Front](https://github.com/tebl/RetroPanel/tree/main/RetroPanel%20SD35VC0%20Front)-module, it does not have any electrical components and is purely here as a cosmetic option. While this one has cutouts for all relevant features for the RetroPanel SD35VC0, it might be a good idea to [find](https://github.com/tebl/RetroPanel/tree/main/faceplates) one that specifically suits your requirements.

If one has not been made available through the repository, it should be rather easy to modify the files belonging to this design and then remove any cutouts or labels that you do not require. Ask nicely and I may even help you.

- [1> Schematic](#1-schematic)
- [2> BOM](#2-bom)

# 1> Schematic
The supplied KiCad files should be sufficient as both a schematic and as a  starting point for ordering PCBs (basically you could just zip the contents of the export folder and upload that on a fabrication site), the schematic is also available in [PDF-format](https://github.com/tebl/RetroPanel/tree/main/documentation/schematic/faceplates) and this is what you'll need to print and work your way through when things fail to work as expected.

# 2> BOM
Most parts should be easy to get a hold of from your favourite local electronic component shop, but given that I don't have access to such shops where I live so everything was based on whatever I could get cheapest from eBay/AliExpress (free shipping, but plan on waiting 3-4 weeks for delivery). 

| Reference | Item | Count | Order  |
| ---| --- | ----- | --- |
| Faceplate PCB  | Fabricate using Gerber files | 1 | PCBWay

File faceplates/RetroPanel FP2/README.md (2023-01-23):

# RetroPanel (FP2)
A faceplate designed to be installed onto the RetroPanels [Front](https://github.com/tebl/RetroPanel/tree/main/RetroPanel%20Front)-module, it does not have any electrical components and is purely here as a cosmetic option. This faceplate only have the cutouts for the 7-segment display and the tool button, making it specifically suitable when used as an external display module for common ISA/PCI POST diagnostic cards. Make sure that you [find one](https://github.com/tebl/RetroPanel/tree/main/faceplates) that specifically suits your requirements, alternatively - use [RetroPanel (FP1)](https://github.com/tebl/RetroPanel/tree/main/faceplates/RetroPanel%20FP1) as a starting when creating your own.

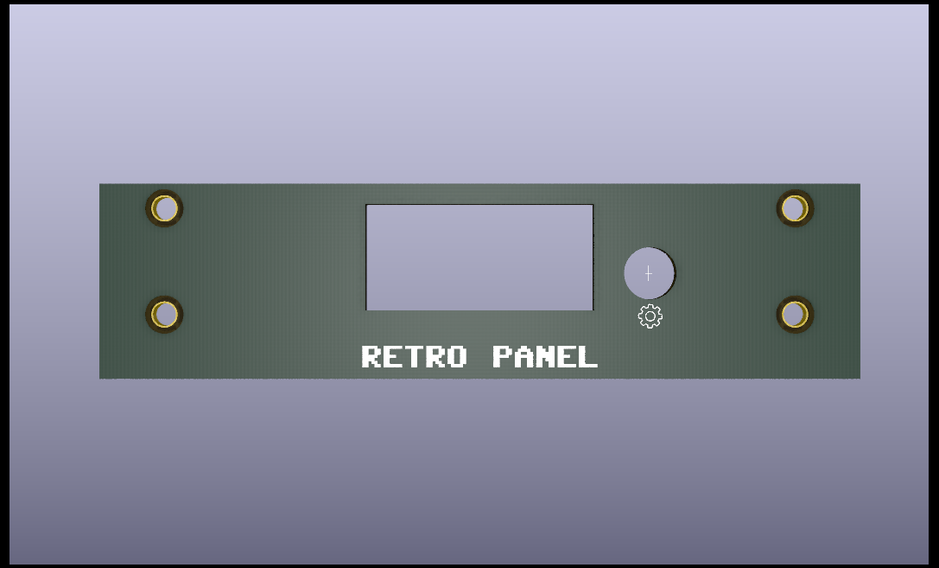
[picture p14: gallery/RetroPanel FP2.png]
What it looks like


- [1> Schematic](#1-schematic)
- [2> BOM](#2-bom)

# 1> Schematic
The supplied KiCad files should be sufficient as both a schematic and as a  starting point for ordering PCBs (basically you could just zip the contents of the export folder and upload that on a fabrication site), the schematic is also available in [PDF-format](https://github.com/tebl/RetroPanel/tree/main/documentation/schematic/faceplates) and this is what you'll need to print and work your way through when things fail to work as expected.

# 2> BOM
Most parts should be easy to get a hold of from your favourite local electronic component shop, but given that I don't have access to such shops where I live so everything was based on whatever I could get cheapest from eBay/AliExpress (free shipping, but plan on waiting 3-4 weeks for delivery). 

| Reference | Item | Count | Order  |
| ---| --- | ----- | --- |
| Faceplate PCB  | Fabricate using Gerber files | 1 | PCBWay

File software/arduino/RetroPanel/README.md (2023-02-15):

# RetroPanel

The functionality of the *RetroPanel* was put together with the *Arduino Pro Micro* in mind, specifically the 5 volt variant running at 16Mhz similar to the classic Uno. Its usage within this project is because it has a second HW-based UART available, perfectly suitable for reliable communication over RS-232 through the level conversion circuitry featured on the RetroPanel.

Consider editing *settings.h* to your liking instead of relying on run-time configuration, especially if you intend on making more than one of them. The serial interface is slightly more suitable for later configuration without a dedicated programming environment, allowing you to spend more time with ancient hardware and less time tethered to a modern laptop.

## Libraries

While the installation of libraries should be handled automatically when using PlatformIO from within Visual Studio Code, but I recognize that many will simply want to get the code onto the board while using the standard *Arduino IDE* instead. In that case you may need to install libraries manually, the ones that are currently needed are as follows:

- [BMP280_DEV](https://github.com/MartinL1/BMP280_DEV)
- [RTCLib](https://github.com/NeiroNx/RTCLib)

Some of these may seem like odd choices, but I found their more popular counterparts to be a bit too resource-heavy for what I could manage to fit onto a single *Arduino Pro Micro*. Be sure that you check that you end up installing the correct library as specified, there are many libraries with similar sounding names.

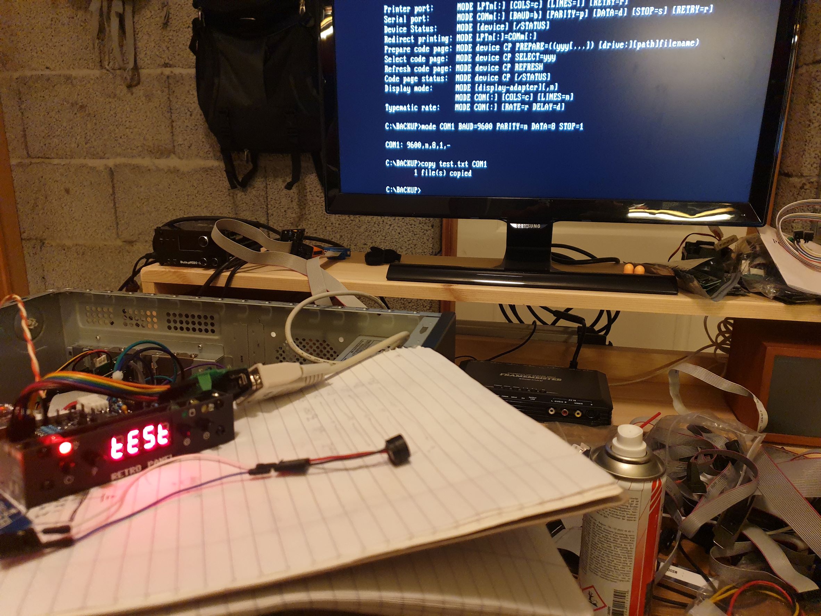
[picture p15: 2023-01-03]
gallery/2022-11-23 00.19.44.jpg

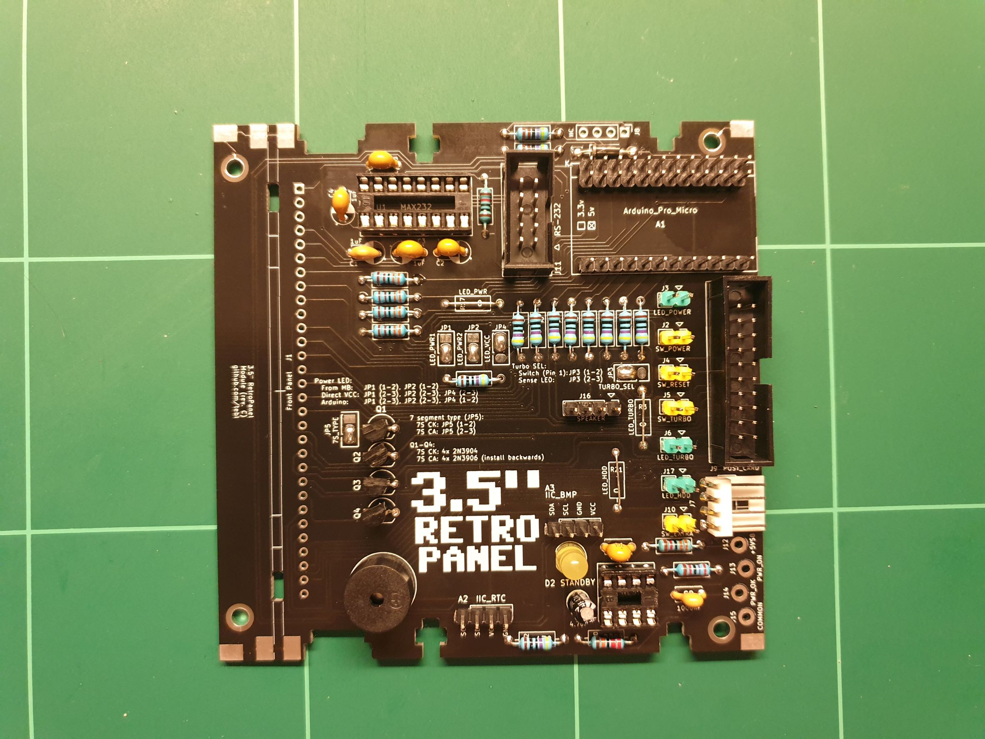
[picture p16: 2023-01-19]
gallery/2023-01-09 14.00.04.jpg

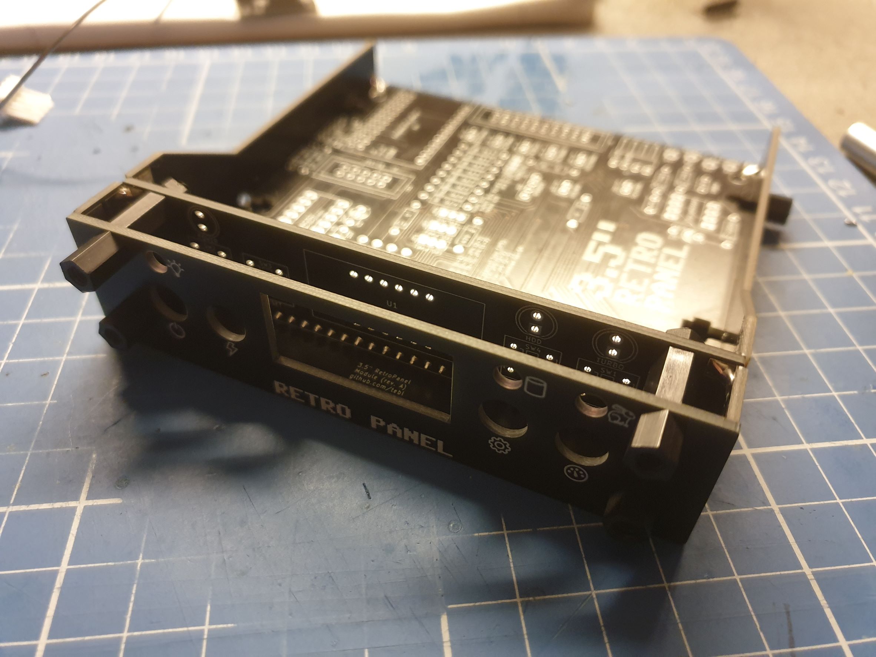
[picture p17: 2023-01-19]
gallery/2022-11-07 02.29.30.jpg

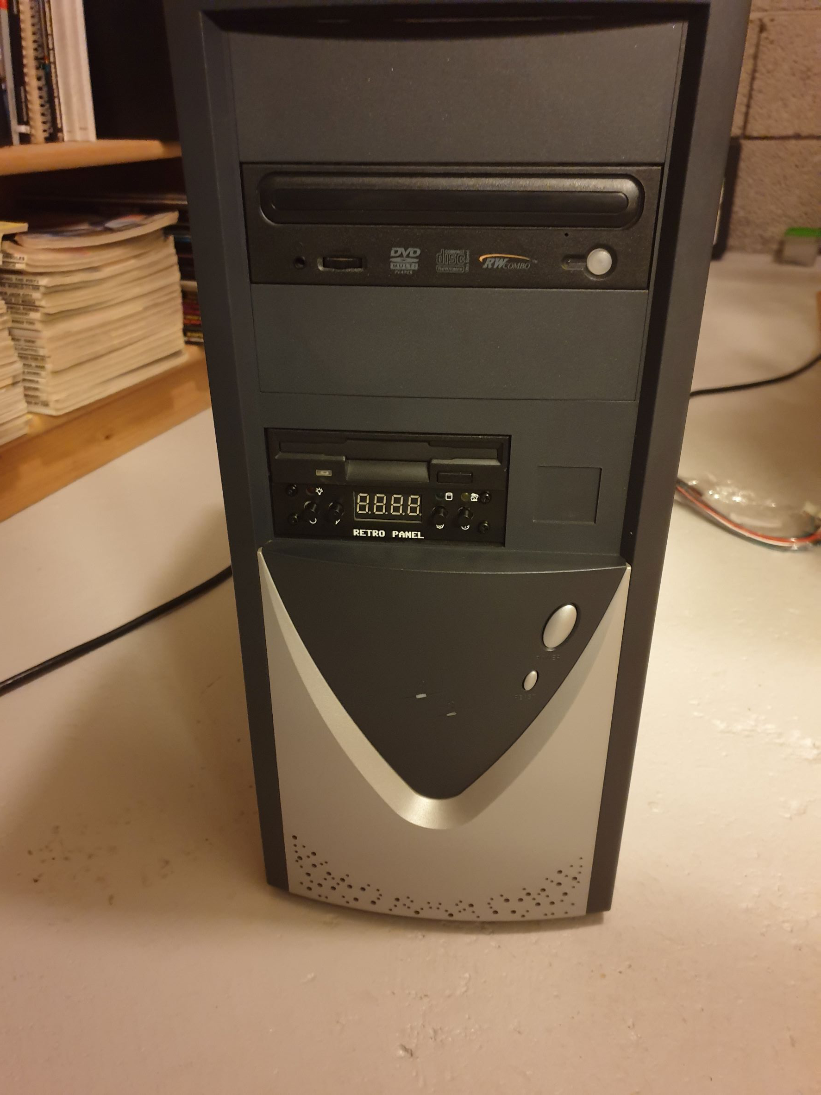
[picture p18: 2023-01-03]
gallery/2022-11-08 02.11.18.jpg

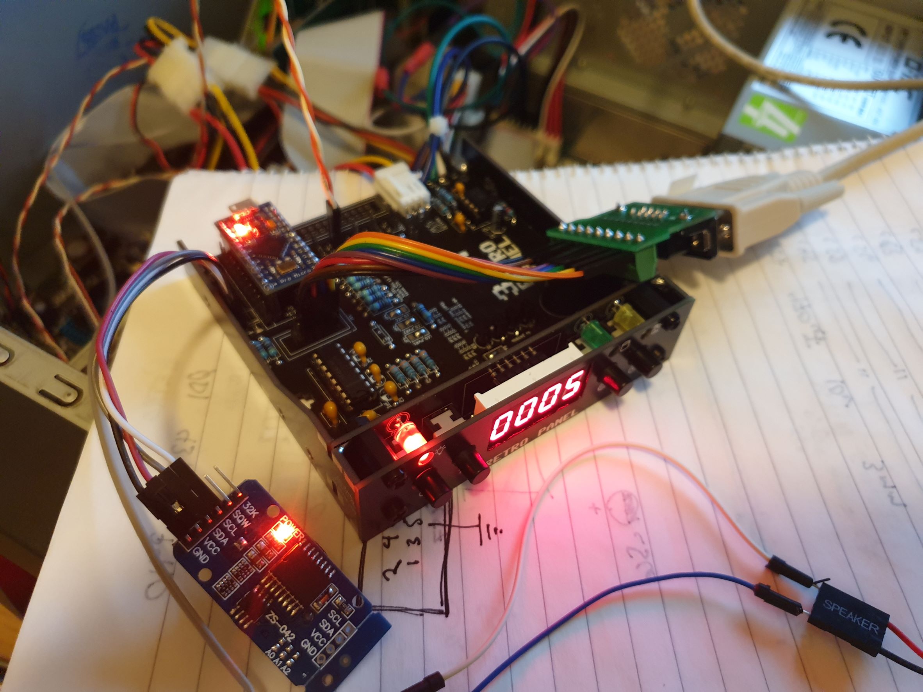
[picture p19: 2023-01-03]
gallery/2022-11-23 00.06.17.jpg

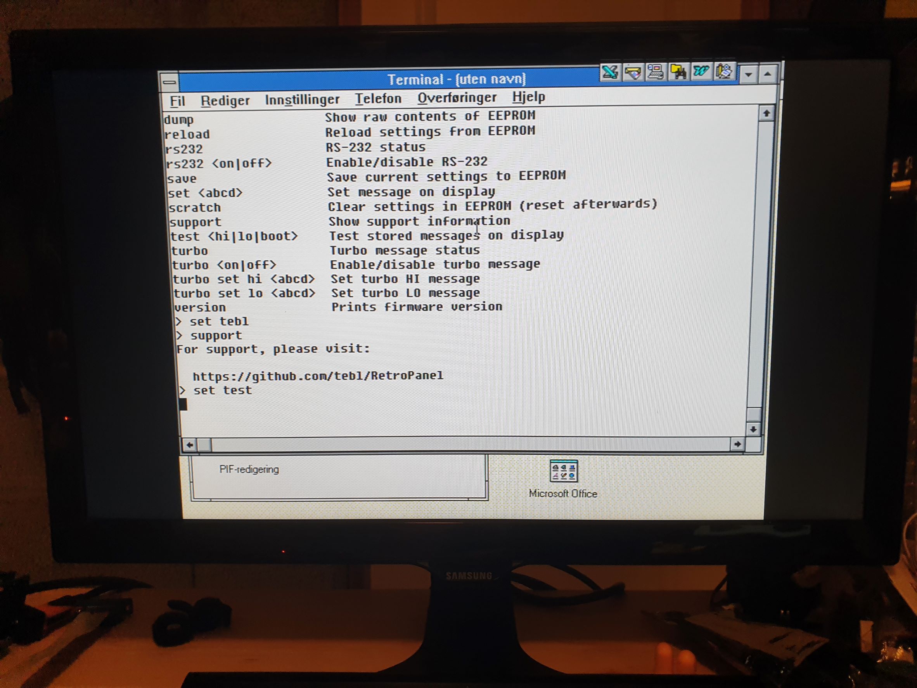
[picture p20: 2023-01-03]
gallery/2022-11-23 00.05.31.jpg

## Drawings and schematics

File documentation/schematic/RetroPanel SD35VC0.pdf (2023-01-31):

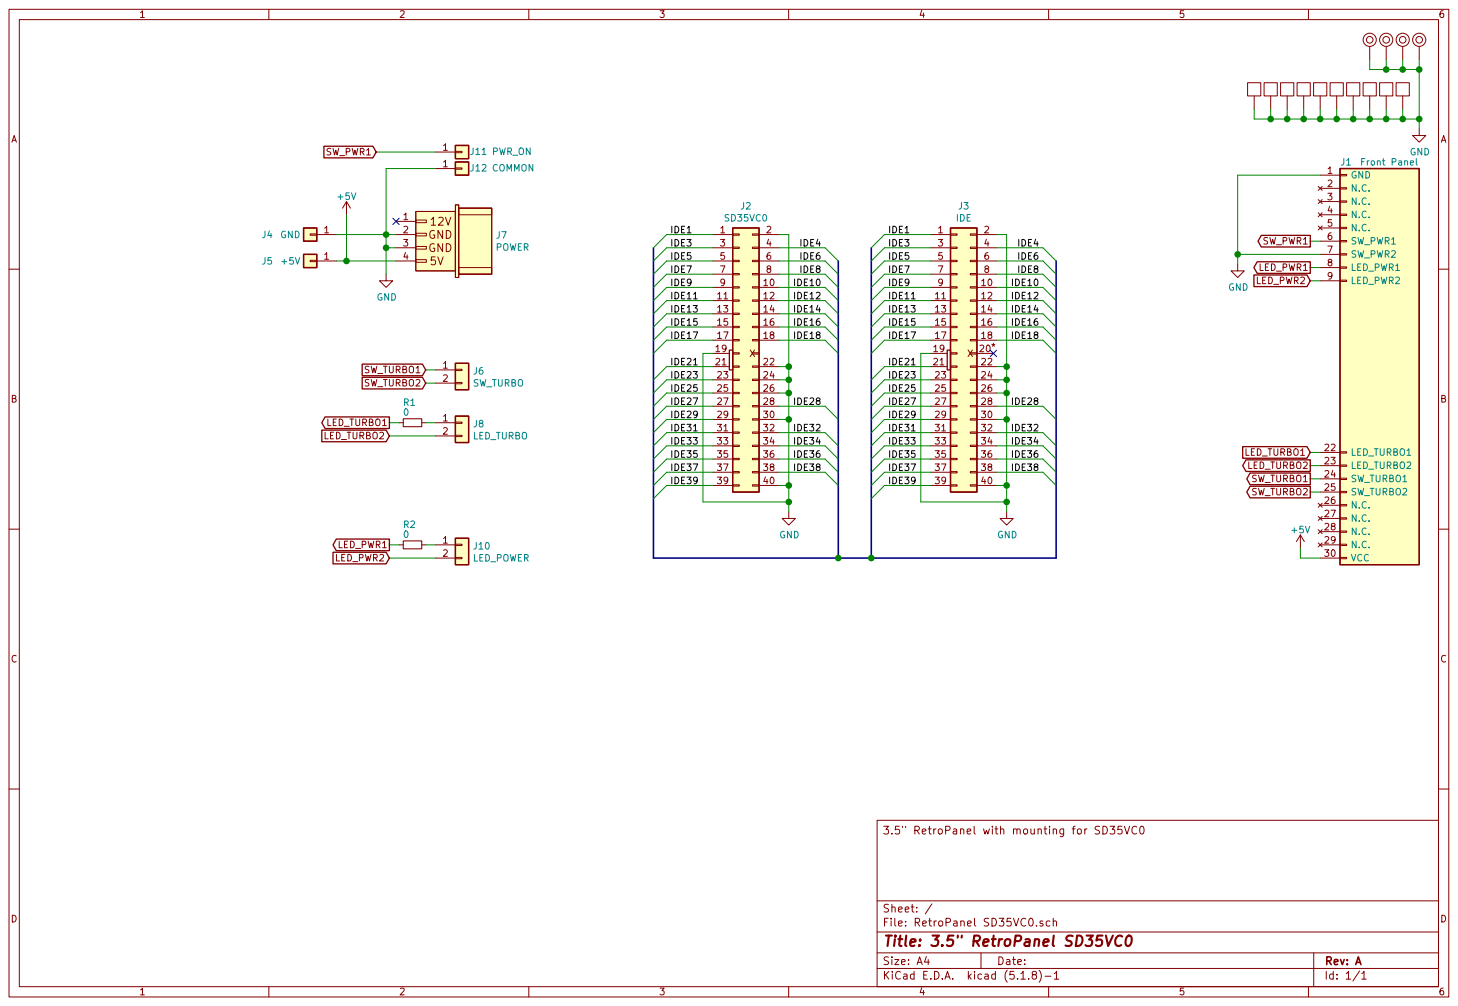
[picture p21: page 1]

File: RetroPanel SD35VC0.sch Sheet: / 3.5" RetroPanel with mounting for SD35VC0

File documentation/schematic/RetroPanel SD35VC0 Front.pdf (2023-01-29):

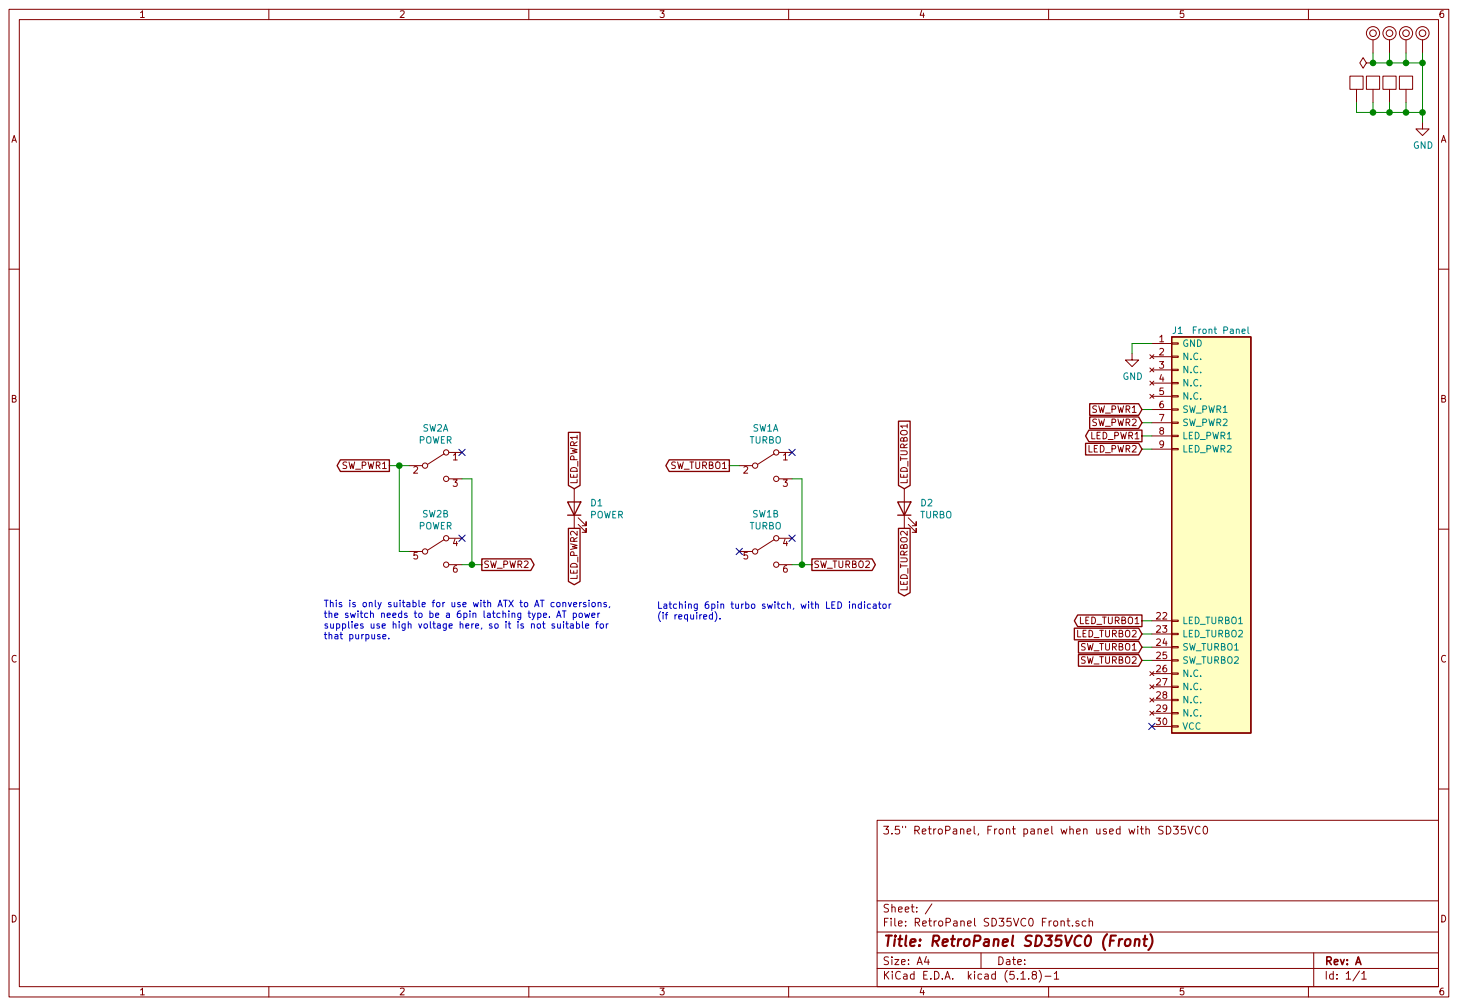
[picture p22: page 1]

Id: 1/1 Title: RetroPanel SD35VC0 (Front) File: RetroPanel SD35VC0 Front.sch Sheet: / 3.5" RetroPanel, Front panel when used with SD35VC0 D2 TURBO

This is only suitable for use with ATX to AT conversions,
the switch needs to be a 6pin latching type. AT power
supplies use high voltage here, so it is not suitable for
that purpuse.

Latching 6pin turbo switch, with LED indicator
(if required).

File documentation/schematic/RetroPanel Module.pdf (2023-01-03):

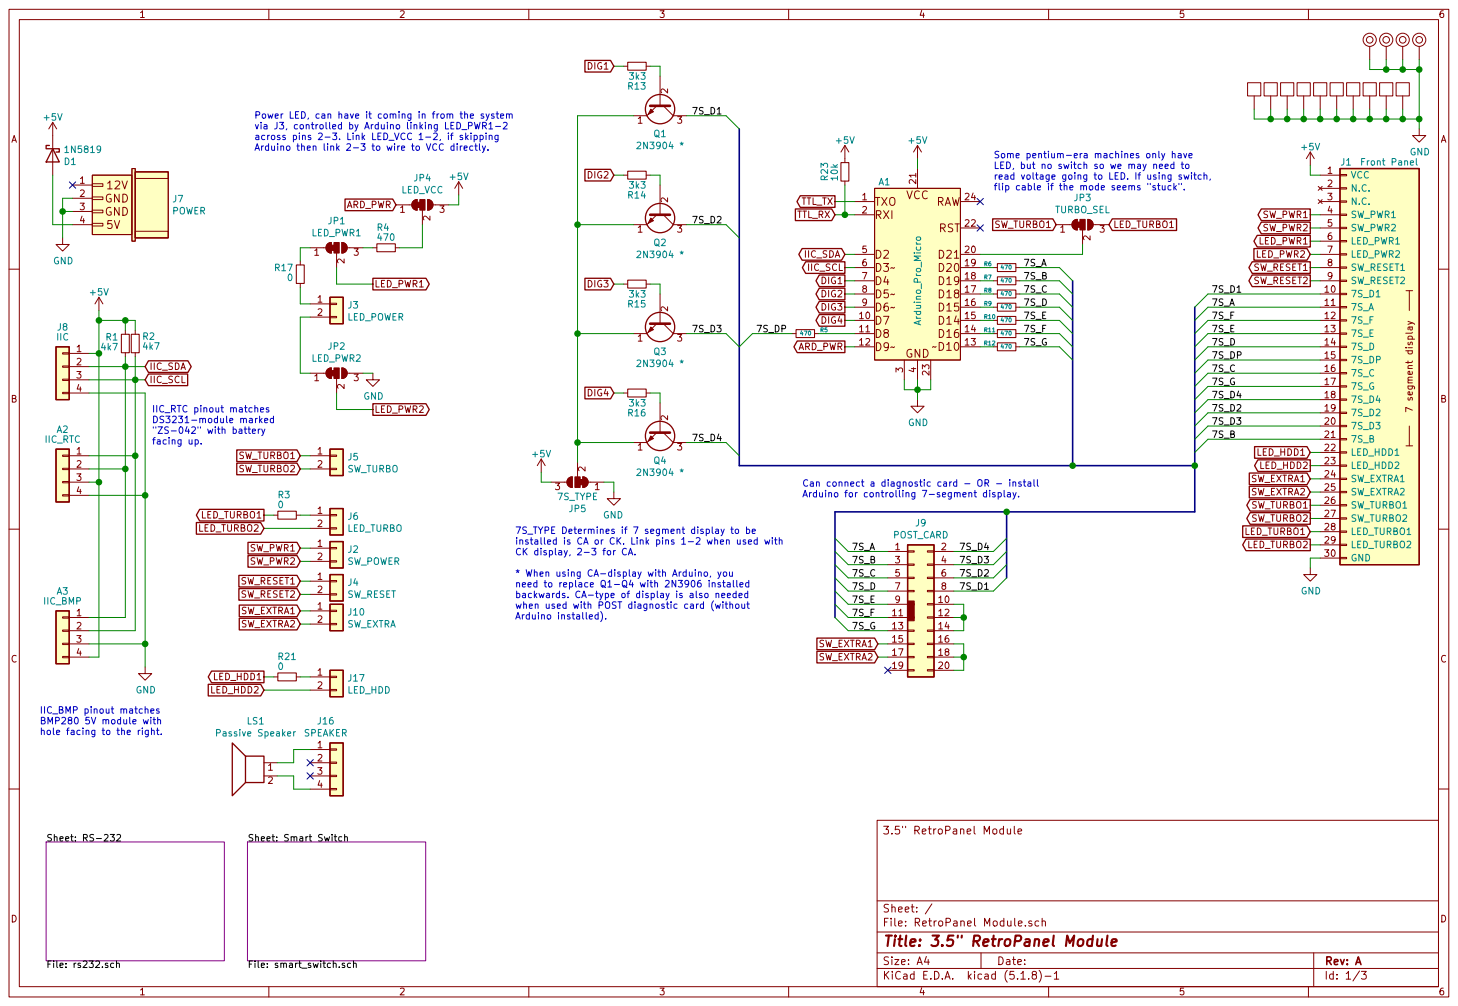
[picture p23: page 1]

Power LED, can have it coming in from the system
via J3, controlled by Arduino linking LED_PWR1-2
across pins 2-3. Link LED_VCC 1-2, if skipping
Arduino then link 2-3 to wire to VCC directly.

Some pentium-era machines only have
LED, but no switch so we may need to
read voltage going to LED. If using switch,
flip cable if the mode seems "stuck".
RAW

IIC_RTC pinout matches DS3231-module marked

Can connect a diagnostic card - OR - install
Arduino for controlling 7-segment display.

7S_TYPE Determines if 7 segment display to be
installed is CA or CK. Link pins 1-2 when used with
CK display, 2-3 for CA.

* When using CA-display with Arduino, you
need to replace Q1-Q4 with 2N3906 installed
backwards. CA-type of display is also needed
when used with POST diagnostic card (without
Arduino installed).

IIC_BMP pinout matches BMP280 5V module with

hole facing to the right.

Id: 1/3 Title: 3.5" RetroPanel Module

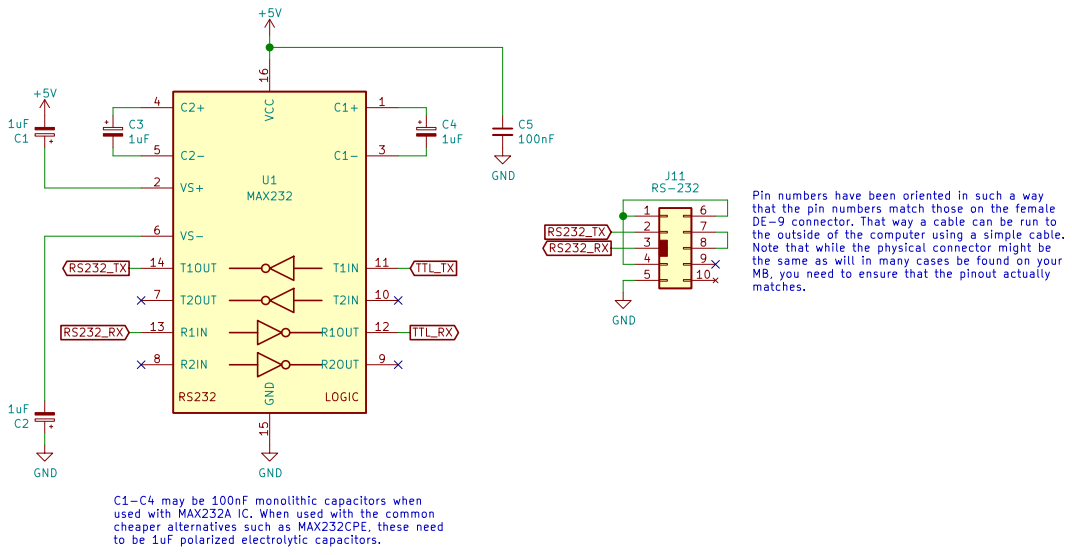
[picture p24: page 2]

Id: 2/3 Title: 3.5" RetroPanel Module (RS-232) File: rs232.sch Sheet: /RS-232/ Handles the circuitry for connecting to the Arduino over RS-232. C5

Pin numbers have been oriented in such a way
that the pin numbers match those on the female
DE-9 connector. That way a cable can be run to
the outside of the computer using a simple cable.
Note that while the physical connector might be
the same as will in many cases be found on your
MB, you need to ensure that the pinout actually matches.

TTL_TX C1-C4 may be 100nF monolithic capacitors when

used with MAX232A IC. When used with the common
cheaper alternatives such as MAX232CPE, these need
to be 1uF polarized electrolytic capacitors.

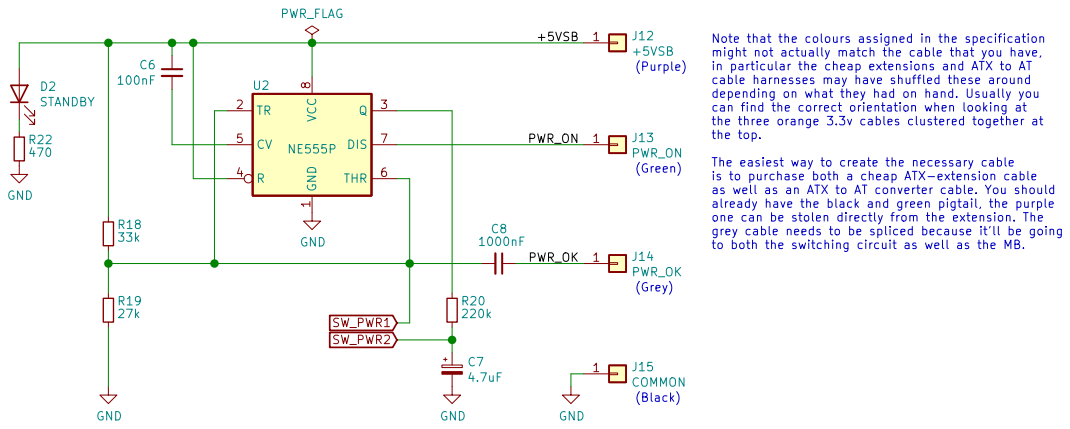
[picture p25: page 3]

Note that the colours assigned in the specification
might not actually match the cable that you have,
in particular the cheap extensions and ATX to AT
cable harnesses may have shuffled these around
depending on what they had on hand. Usually you
can find the correct orientation when looking at
the three orange 3.3v cables clustered together at
the top.

The easiest way to create the necessary cable
is to purchase both a cheap ATX-extension cable
as well as an ATX to AT converter cable. You should
already have the black and green pigtail, the purple
one can be stolen directly from the extension. The
grey cable needs to be spliced because it'll be going
to both the switching circuit as well as the MB.

to shut down when one of its outputs have been shorted. If the circuit is not needed, a
latching switch can be installed on the front and then wired to the ATX to AT cables.

File: smart_switch.sch Sheet: /Smart Switch/
Id: 3/3 Title: 3.5" RetroPanel Module (Smart Switch)

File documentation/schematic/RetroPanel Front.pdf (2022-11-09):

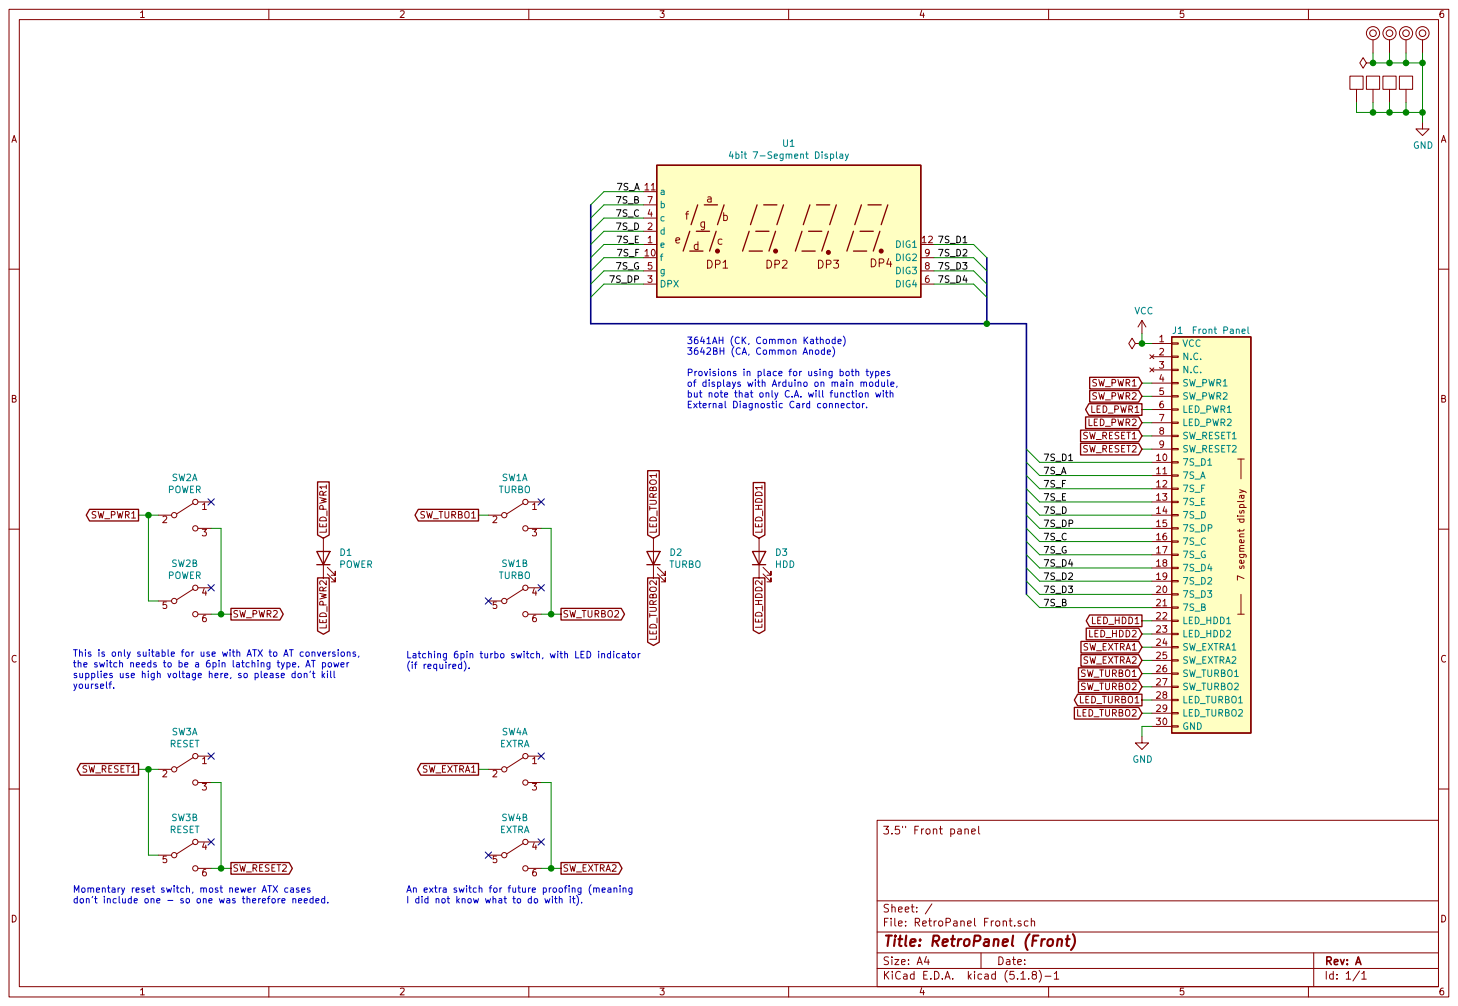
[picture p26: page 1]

Provisions in place for using both types
of displays with Arduino on main module,
but note that only C.A. will function with
External Diagnostic Card connector.

This is only suitable for use with ATX to AT conversions,
the switch needs to be a 6pin latching type. AT power
supplies use high voltage here, so please don't kill
yourself.

Latching 6pin turbo switch, with LED indicator
(if required).

I did not know what to do with it).

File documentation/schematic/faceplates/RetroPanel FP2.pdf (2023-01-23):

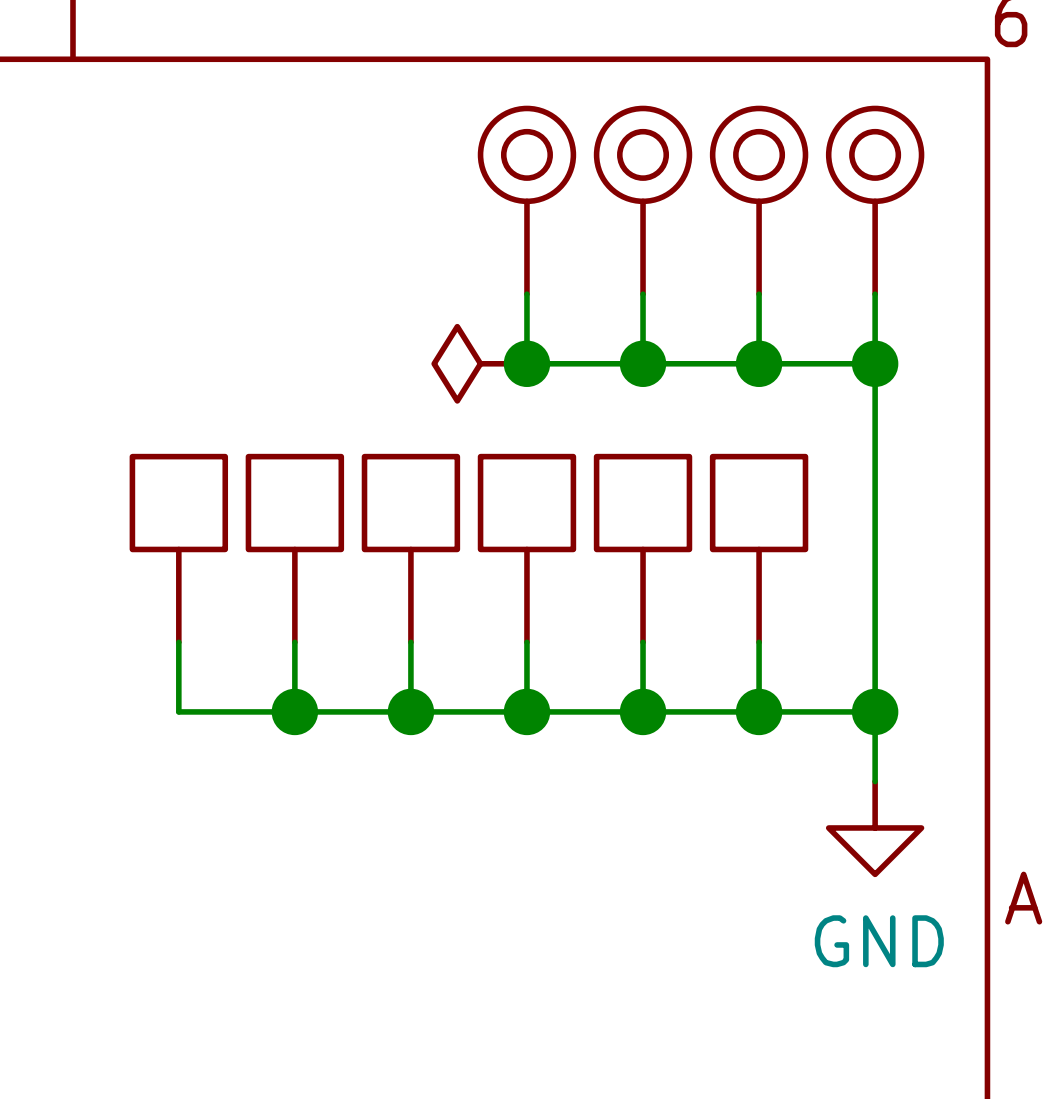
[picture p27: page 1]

Only features cutouts for the features used by POST card,
Id: 1/1 Title: RetroPanel (Faceplate FP2) File: RetroPanel FP2.sch Sheet: / 7-segment display (CA) and tool button.

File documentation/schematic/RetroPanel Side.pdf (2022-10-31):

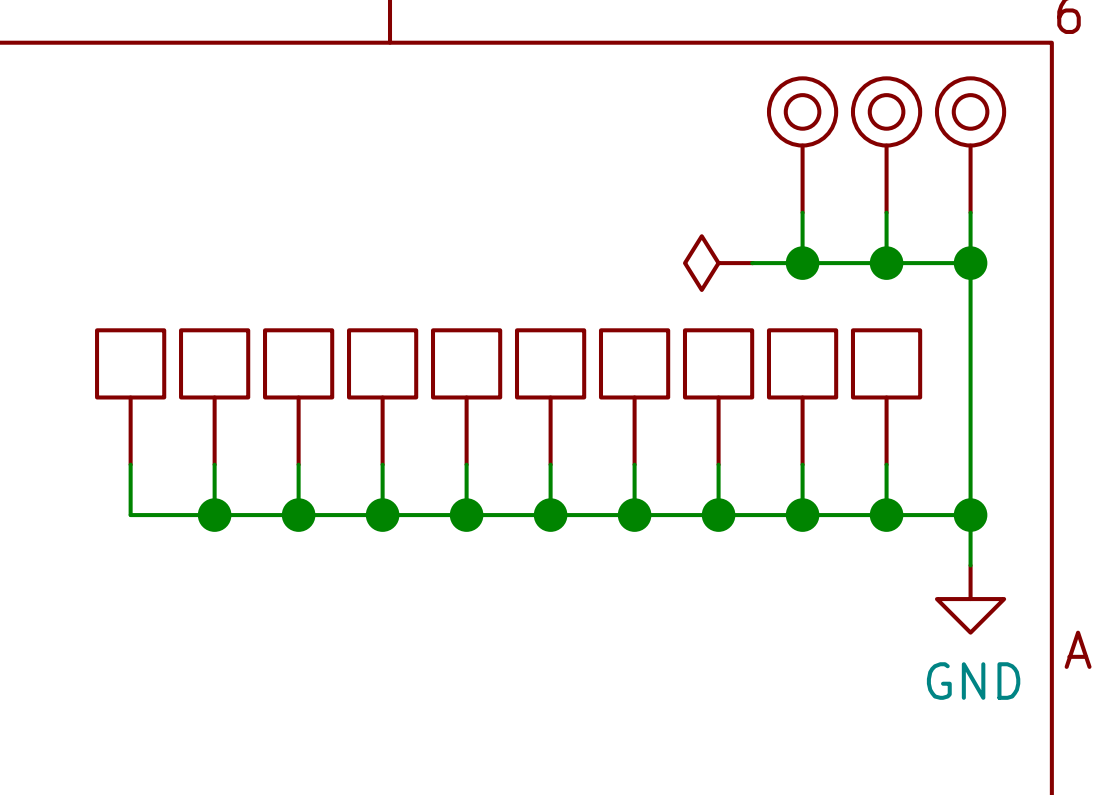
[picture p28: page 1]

Id: 1/1 Title: BulkyModem (Side) File: RetroPanel Side.sch Sheet: / 3.5" Side panels

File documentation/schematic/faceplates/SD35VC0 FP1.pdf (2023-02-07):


Id: 1/1 Title: RetroPanel SD35VC0 (Faceplate FP1) File: SD35VC0 FP1.sch Sheet: / A faceplate with provisions for most features.

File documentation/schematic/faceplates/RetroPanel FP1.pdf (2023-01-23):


Id: 1/1 Title: RetroPanel (Faceplate FP1) File: RetroPanel FP1.sch Sheet: / A faceplate with provisions for most features.

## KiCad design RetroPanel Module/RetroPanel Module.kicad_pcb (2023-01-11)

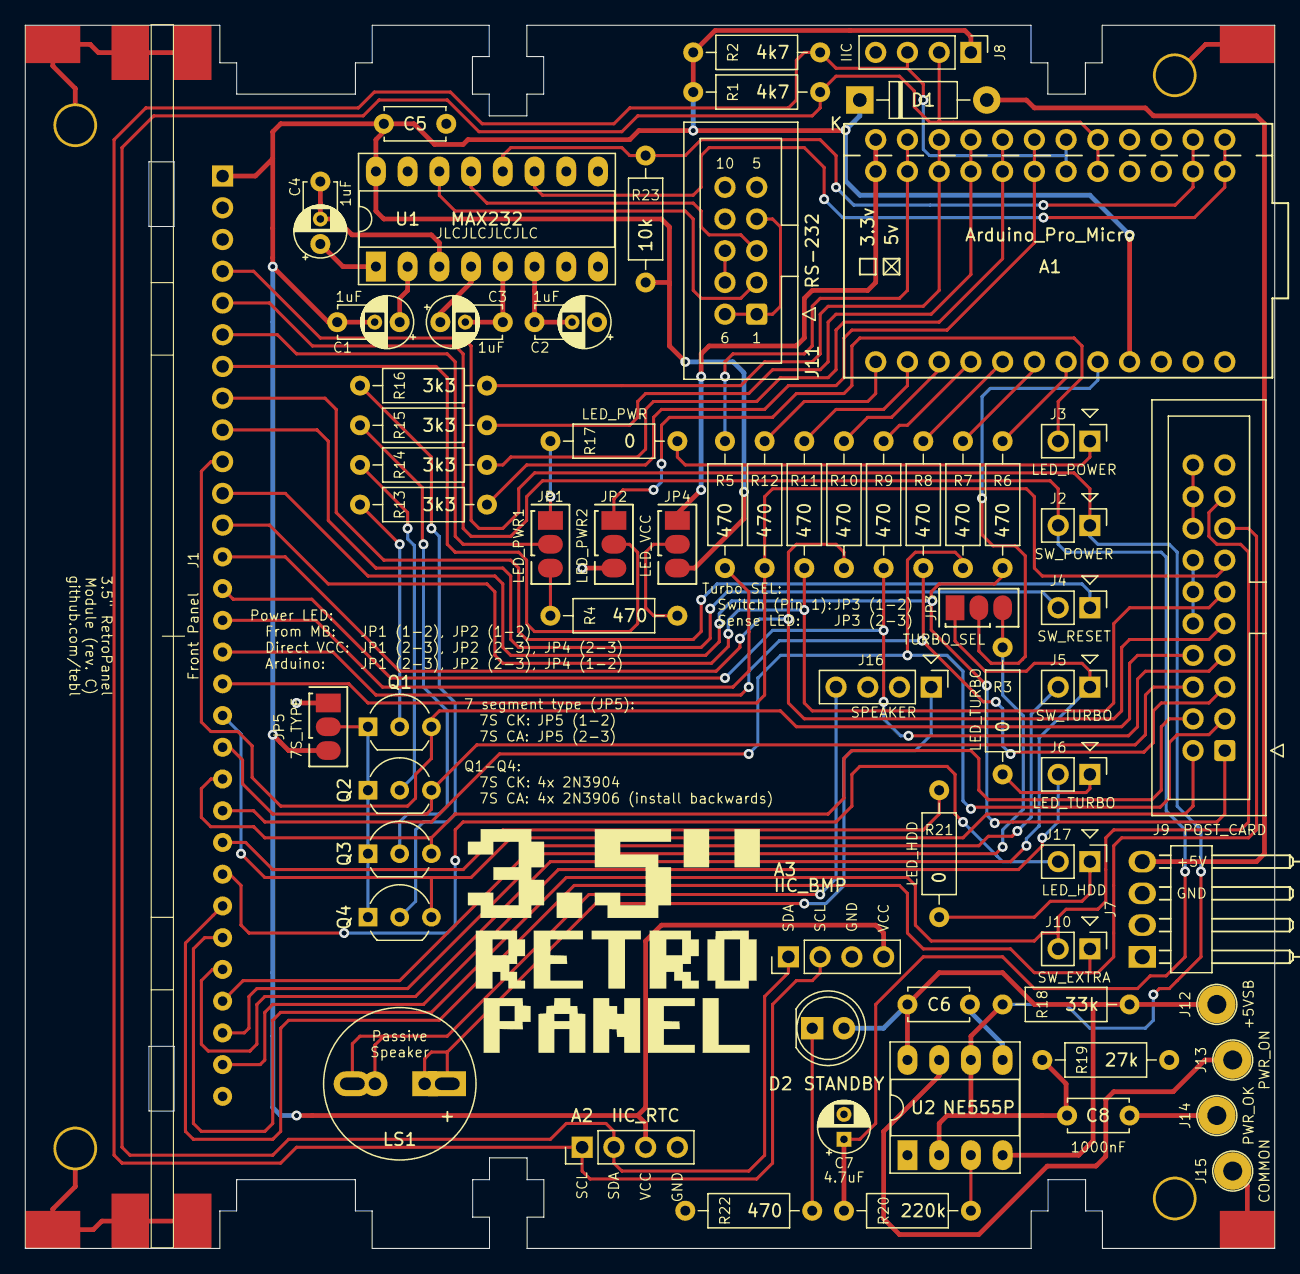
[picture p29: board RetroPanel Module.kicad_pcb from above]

Board: 2 copper layers, 100.0 x 97.9 mm, 79 parts (0 on the bottom side), 79 nets.

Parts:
A1: Arduino_Pro_Micro
A2: IIC_RTC; DS3231_ZS-042
A3: IIC_BMP; BMP280-5V
C1, C2, C3, C4: 1uF; CP_Radial_D4.0mm_P2.00mm_Custom
C5, C6: 100nF; C_Disc_D4.7mm_W2.5mm_P5.00mm
C7: 4.7uF; CP_Radial_D4.0mm_P2.00mm
C8: 1000nF; C_Disc_D4.7mm_W2.5mm_P5.00mm
D1: 1N5819; D_DO-41_SOD81_P10.16mm_Horizontal
D2: STANDBY; LED_D5.0mm
J1: Front Panel; Module_Panel
J2: SW_POWER; PinHeader_1x02_P2.54mm_Vertical
J3: LED_POWER; PinHeader_1x02_P2.54mm_Vertical
J4: SW_RESET; PinHeader_1x02_P2.54mm_Vertical
J5: SW_TURBO; PinHeader_1x02_P2.54mm_Vertical
J6: LED_TURBO; PinHeader_1x02_P2.54mm_Vertical
J7: POWER; Molex_KK-254_1x04_P2.54mm_Horizontal
J8: IIC; PinHeader_1x04_P2.54mm_Vertical
J9: POST_CARD; IDC-Header_2x10_P2.54mm_Vertical
J10: SW_EXTRA; PinHeader_1x02_P2.54mm_Vertical
J11: RS-232; IDC-RS-232-Female
J12: +5VSB; PSU_Wire
J13: PWR_ON; PSU_Wire
J14: PWR_OK; PSU_Wire
J15: COMMON; PSU_Wire
J16: SPEAKER; PinHeader_1x04_P2.54mm_Vertical
J17: LED_HDD; PinHeader_1x02_P2.54mm_Vertical
JP1: LED_PWR1; select
JP2: LED_PWR2; select
JP3: TURBO_SEL; select
JP4: LED_VCC; select
JP5: 7S_TYPE; select
LS1: Passive Speaker; Buzzer_12x9.5RM7.6
M1, M2, M3, M16: Mounting_Pin; M3_pin
M5, M8, M9, M10, M11, M12, M13, M15: Mounting_Pad; Pad_pin
M7, M14: Mounting_Pad; B.Pad_pin
Q1, Q2, Q3, Q4: 2N3904 *; TO-92_Inline_Wide
R1, R2: 4k7; R_Axial_DIN0207_L6.3mm_D2.5mm_P10.16mm_Horizontal
R3, R17, R21: 0; R_Axial_DIN0207_L6.3mm_D2.5mm_P10.16mm_Horizontal
R4, R5, R6, R7, R8, R9, R10, R11, R12, R22: 470; R_Axial_DIN0207_L6.3mm_D2.5mm_P10.16mm_Horizontal
R13, R14, R15, R16: 3k3; R_Axial_DIN0207_L6.3mm_D2.5mm_P10.16mm_Horizontal
R18: 33k; R_Axial_DIN0207_L6.3mm_D2.5mm_P10.16mm_Horizontal
R19: 27k; R_Axial_DIN0207_L6.3mm_D2.5mm_P10.16mm_Horizontal
R20: 220k; R_Axial_DIN0207_L6.3mm_D2.5mm_P10.16mm_Horizontal
R23: 10k; R_Axial_DIN0207_L6.3mm_D2.5mm_P10.16mm_Horizontal
U1: MAX232; DIP-16_W7.62mm_Socket_LongPads
U2: NE555P; DIP-8_W7.62mm_Socket_LongPads

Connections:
+5V: A1.21, A2.3, A3.4, C1.2, C5.1, D1.1, J1.1, J8.1, JP4.3, JP5.3, R1.1, R2.2, R23.1, U1.16
/7S_A: J1.11, J9.1, R6.1
/7S_B: J1.21, J9.3, R7.1
/7S_C: J1.16, J9.5, R8.1
/7S_D: J1.14, J9.7, R9.1
/7S_D1: J1.10, J9.8, Q1.3
/7S_D2: J1.19, J9.6, Q2.3
/7S_D3: J1.20, J9.4, Q3.3
/7S_D4: J1.18, J9.2, Q4.3
/7S_DP: J1.15, R5.1
/7S_E: J1.13, J9.9, R10.1
/7S_F: J1.12, J9.11, R11.1
/7S_G: J1.17, J9.13, R12.1
/Smart Switch/+5VSB: C6.1, D2.2, J12.1, R18.2, U2.4, U2.8
/Smart Switch/PWR_OK: C8.1, J14.1
/Smart Switch/PWR_ON: J13.1, U2.7
ARD_PWR: A1.12, JP4.1
DIG1: A1.7, R13.1
DIG2: A1.8, R14.1
DIG3: A1.9, R15.1
DIG4: A1.10, R16.1
GND: A1.3, A1.4, A1.23, A2.4, A3.3, C2.1, C5.2, C7.2, J1.30, J7.2, J7.3, J8.4, J11.5, J15.1, JP2.3, JP5.1, M1.1, M2.1, M3.1, M5.1, M7.1, M8.1, M9.1, M10.1, M11.1, M12.1, M13.1, M14.1, M15.1, M16.1, R19.1, R22.1, U1.15, U2.1
IIC_SCL: A1.6, A2.1, A3.2, J8.3, R2.1
IIC_SDA: A1.5, A2.2, A3.1, J8.2, R1.2
LED_HDD1: J1.22, R21.2
LED_HDD2: J1.23, J17.2
LED_PWR1: J1.6, JP1.2
LED_PWR2: J1.7, JP2.2
LED_TURBO1: J1.28, JP3.3, R3.2
LED_TURBO2: J1.29, J6.2
unnamed: A1.11, R5.2
unnamed: A1.13, R12.2
unnamed: A1.14, R11.2
unnamed: A1.15, R10.2
unnamed: A1.16, R9.2
unnamed: A1.17, R8.2
unnamed: A1.18, R7.2
unnamed: A1.19, R6.2
unnamed: A1.20, JP3.2
unnamed: C1.1, U1.2
unnamed: C2.2, U1.6
unnamed: C3.1, U1.4
unnamed: C3.2, U1.5
unnamed: C4.1, U1.1
unnamed: C4.2, U1.3
unnamed: C6.2, U2.5
unnamed: D1.2, J7.4
unnamed: D2.1, R22.2
unnamed: J3.1, R17.2
unnamed: J3.2, JP2.1
unnamed: J6.1, R3.1
unnamed: J9.10, J9.12, J9.14
unnamed: J9.16, J9.18, J9.20
unnamed: J11.1, J11.4, J11.6
unnamed: J11.7, J11.8
unnamed: J16.1, LS1.1
unnamed: J16.4, LS1.2
unnamed: J17.1, R21.1
unnamed: JP1.1, R17.1
unnamed: JP1.3, R4.2
unnamed: JP4.2, R4.1
unnamed: JP5.2, Q1.1, Q2.1, Q3.1, Q4.1
unnamed: Q1.2, R13.2
unnamed: Q2.2, R14.2
unnamed: Q3.2, R15.2
unnamed: Q4.2, R16.2
unnamed: R20.2, U2.3
RS232_RX: J11.3, U1.13
RS232_TX: J11.2, U1.14
SW_EXTRA1: J1.24, J9.15, J10.1
SW_EXTRA2: J1.25, J9.17, J10.2
SW_PWR1: C8.2, J1.4, J2.1, R18.1, R19.2, U2.2, U2.6
SW_PWR2: C7.1, J1.5, J2.2, R20.1
SW_RESET1: J1.8, J4.1
SW_RESET2: J1.9, J4.2
SW_TURBO1: J1.26, J5.1, JP3.1
SW_TURBO2: J1.27, J5.2
TTL_RX: A1.2, R23.2, U1.12
TTL_TX: A1.1, U1.11

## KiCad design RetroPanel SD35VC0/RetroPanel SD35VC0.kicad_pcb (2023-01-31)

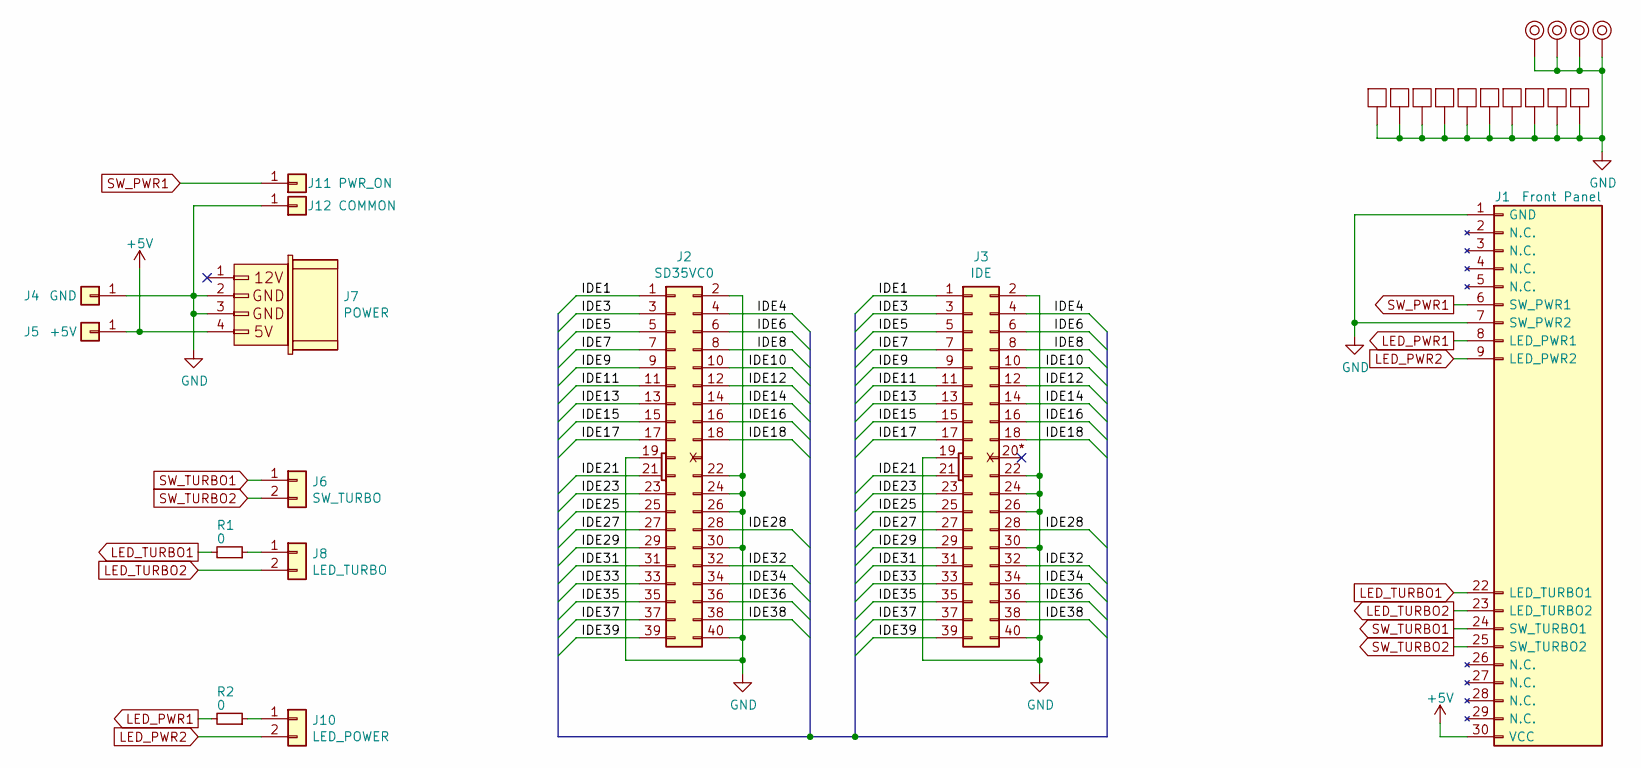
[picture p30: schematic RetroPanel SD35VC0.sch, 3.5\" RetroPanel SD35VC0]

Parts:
J1: Front Panel; SD35VC0_Module_Panel
J2: SD35VC0
J3: IDE; IDC-Header_2x20_P2.54mm_Vertical
J4: GND; PSU_Wire
J5: +5V; PSU_Wire
J6: SW_TURBO; PinHeader_1x02_P2.54mm_Vertical
J7: POWER; Molex_KK-254_1x04_P2.54mm_Horizontal
J8: LED_TURBO; PinHeader_1x02_P2.54mm_Vertical
J10: LED_POWER; PinHeader_1x02_P2.54mm_Vertical
J11: PWR_ON; PSU_Wire
J12: COMMON; PSU_Wire
M1, M2, M3, M16: Mounting_Pin; M3_pin
M5, M8, M9, M10, M11, M12, M13, M15: Mounting_Pad; Pad_pin
M7, M14: Mounting_Pad; B.Pad_pin
R1, R2: 0; R_Axial_DIN0207_L6.3mm_D2.5mm_P10.16mm_Horizontal

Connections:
+5V: J1.30 (VCC), J5.1, J7.4
/IDE1: J2.1, J3.1
/IDE3: J2.3, J3.3
/IDE4: J2.4, J3.4
/IDE5: J2.5, J3.5
/IDE6: J2.6, J3.6
/IDE7: J2.7, J3.7
/IDE8: J2.8, J3.8
/IDE9: J2.9, J3.9
/IDE10: J2.10, J3.10
/IDE11: J2.11, J3.11
/IDE12: J2.12, J3.12
/IDE13: J2.13, J3.13
/IDE14: J2.14, J3.14
/IDE15: J2.15, J3.15
/IDE16: J2.16, J3.16
/IDE17: J2.17, J3.17
/IDE18: J2.18, J3.18
/IDE21: J2.21, J3.21
/IDE23: J2.23, J3.23
/IDE25: J2.25, J3.25
/IDE27: J2.27, J3.27
/IDE28: J2.28, J3.28
/IDE29: J2.29, J3.29
/IDE31: J2.31, J3.31
/IDE32: J2.32, J3.32
/IDE33: J2.33, J3.33
/IDE34: J2.34, J3.34
/IDE35: J2.35, J3.35
/IDE36: J2.36, J3.36
/IDE37: J2.37, J3.37
/IDE38: J2.38, J3.38
/IDE39: J2.39, J3.39
GND: J1.1 (GND), J1.7 (SW_PWR2), J2.2, J2.19, J2.22, J2.24, J2.26, J2.30, J2.40, J3.2, J3.19, J3.22, J3.24, J3.26, J3.30, J3.40, J4.1, J7.2, J7.3, J12.1, M1.1, M2.1, M3.1, M5.1, M7.1, M8.1, M9.1, M10.1, M11.1, M12.1, M13.1, M14.1, M15.1, M16.1
LED_PWR1: J1.8 (LED_PWR1), R2.2
LED_PWR2: J1.9 (LED_PWR2), J10.2
LED_TURBO1: J1.22 (LED_TURBO1), R1.2
LED_TURBO2: J1.23 (LED_TURBO2), J8.2
unnamed: J8.1, R1.1
unnamed: J10.1, R2.1
SW_PWR1: J1.6 (SW_PWR1), J11.1
SW_TURBO1: J1.24 (SW_TURBO1), J6.1
SW_TURBO2: J1.25 (SW_TURBO2), J6.2

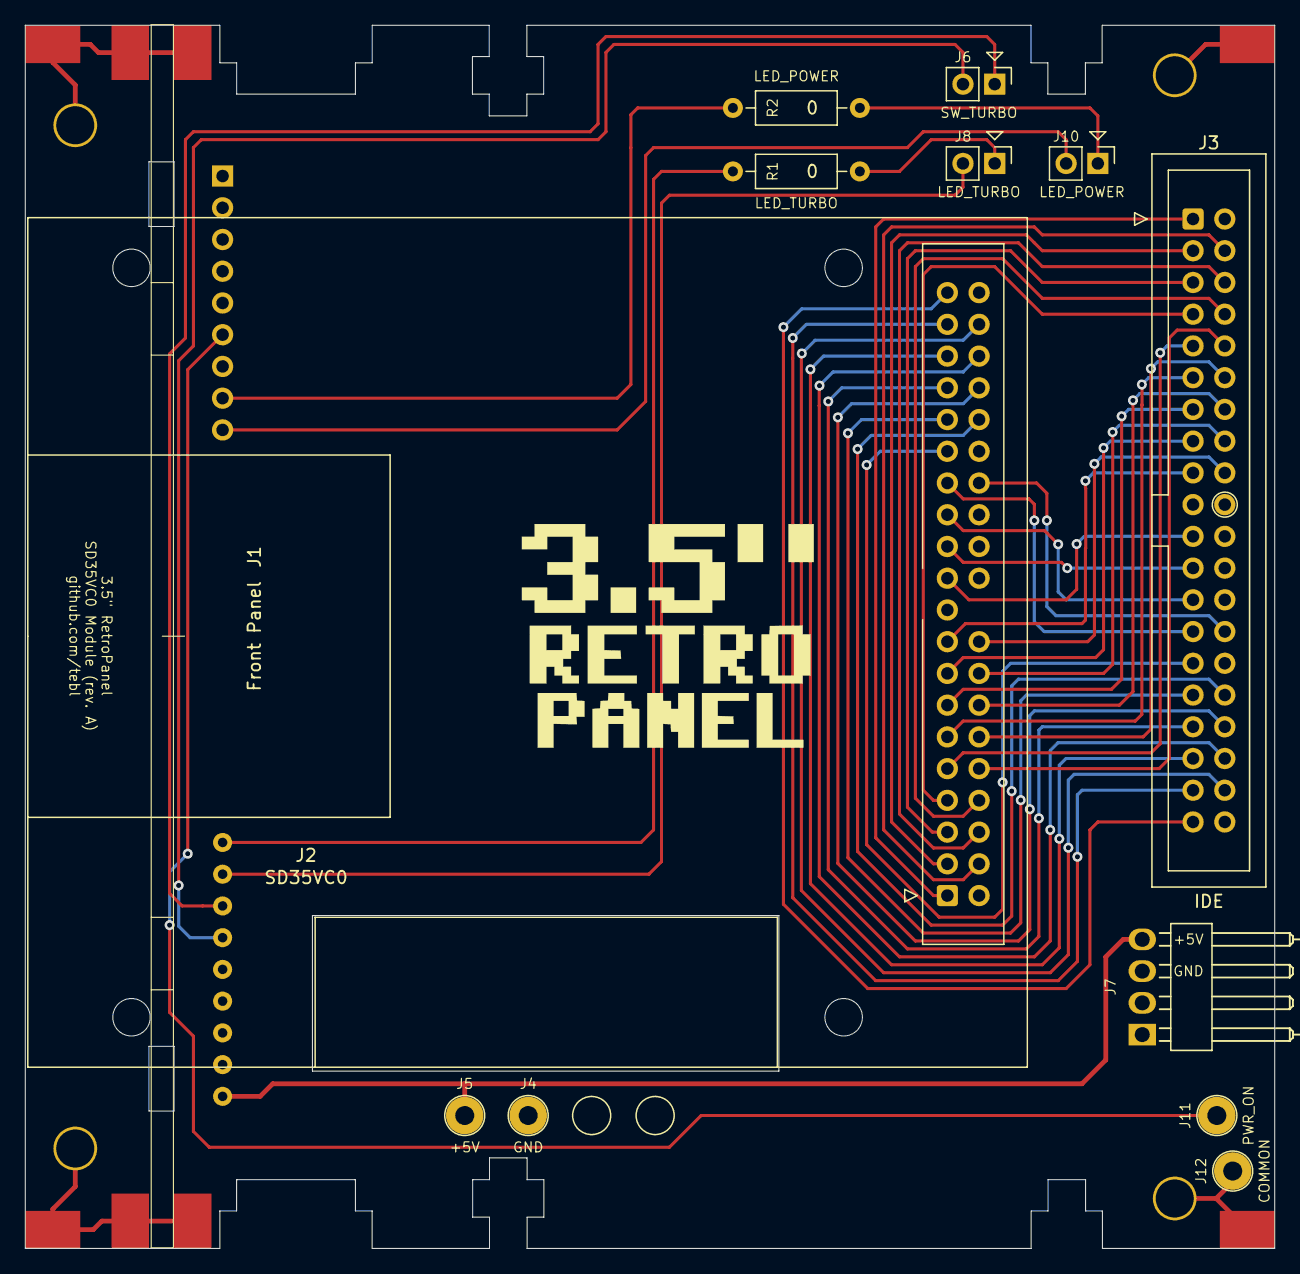
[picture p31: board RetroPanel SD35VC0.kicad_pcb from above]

Board: 2 copper layers, 100.0 x 97.9 mm, 27 parts (0 on the bottom side), 43 nets.

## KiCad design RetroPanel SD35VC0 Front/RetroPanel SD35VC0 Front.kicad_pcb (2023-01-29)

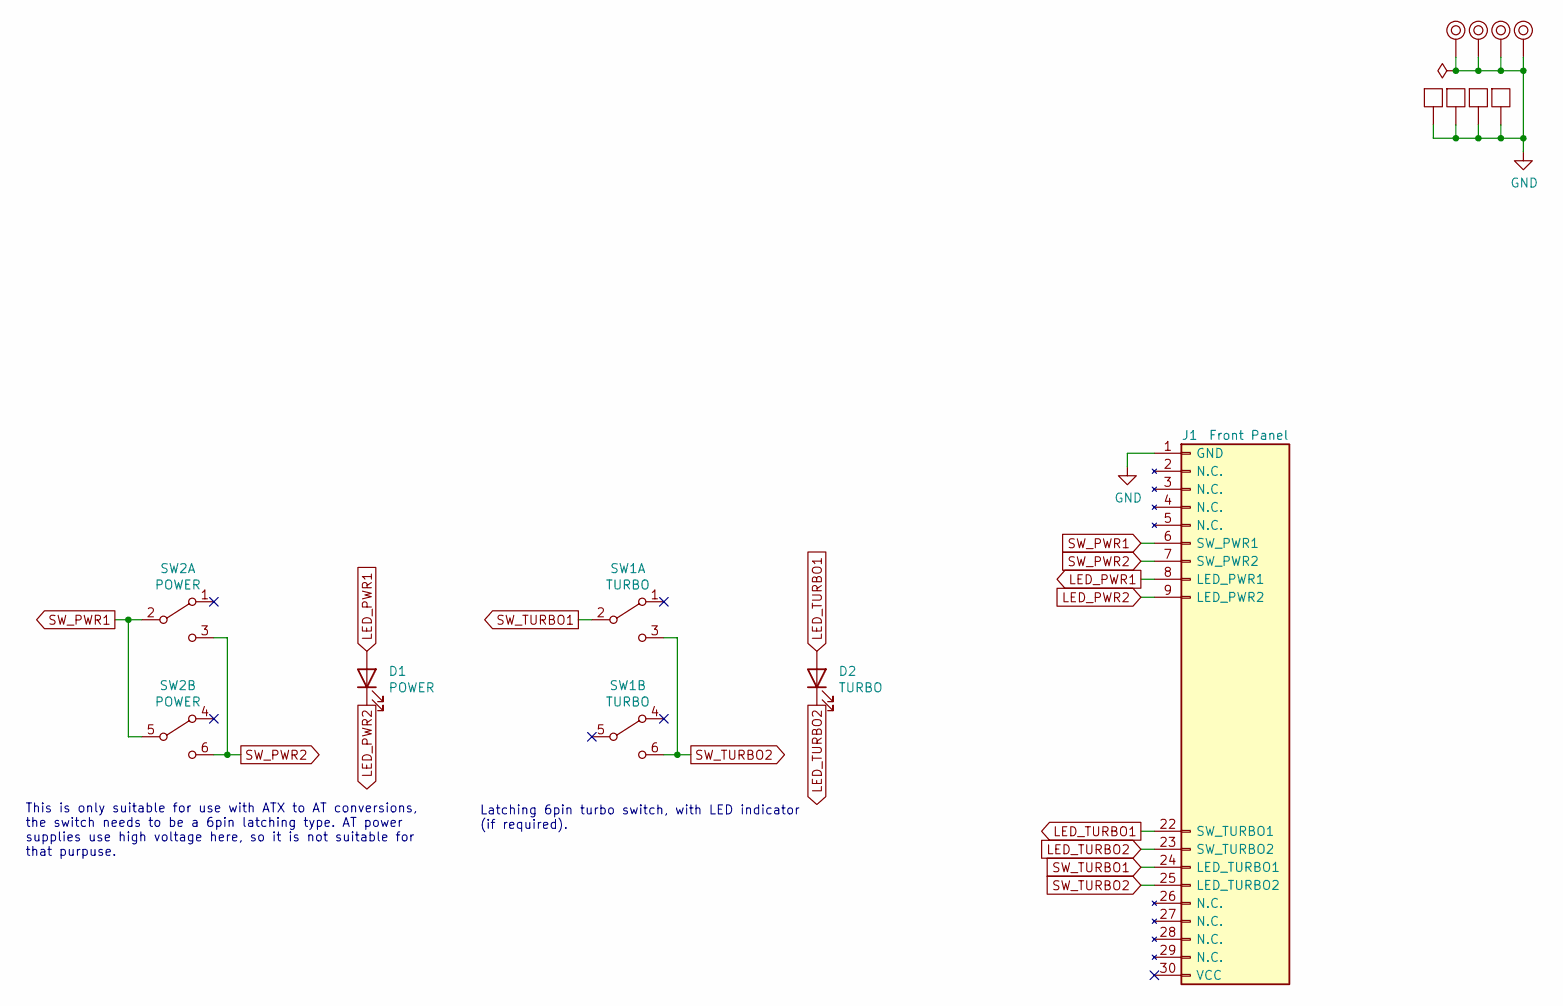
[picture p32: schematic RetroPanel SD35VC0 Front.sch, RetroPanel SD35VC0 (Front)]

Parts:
D1: POWER; LED_D5.0mm
D2: TURBO; LED_D5.0mm
J1: Front Panel; SD35VC0_PinHeader_1x30_P2.54mm_Horizontal
M1, M2, M3, M4: Mounting_Pin; M3_pin
M5, M7, M9, M10: Mounting_Pad; Pad_pin
SW1: TURBO; dpdt_switch_black
SW2: POWER; dpdt_switch_black

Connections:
GND: J1.1 (GND), M1.1, M2.1, M3.1, M4.1, M5.1, M7.1, M9.1, M10.1
LED_PWR1: D1.2 (A), J1.8 (LED_PWR1)
LED_PWR2: D1.1 (K), J1.9 (LED_PWR2)
LED_TURBO1: D2.2 (A), J1.22 (SW_TURBO1)
LED_TURBO2: D2.1 (K), J1.23 (SW_TURBO2)
SW_PWR1: J1.6 (SW_PWR1), SW2.2 (B), SW2.5 (B)
SW_PWR2: J1.7 (SW_PWR2), SW2.3 (C), SW2.6 (C)
SW_TURBO1: J1.24 (LED_TURBO1), SW1.2 (B)
SW_TURBO2: J1.25 (LED_TURBO2), SW1.3 (C), SW1.6 (C)

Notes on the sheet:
This is only suitable for use with ATX to AT conversions, the switch needs to be a 6pin latching type. AT power supplies use high voltage here, so it is not suitable for that purpuse.
Latching 6pin turbo switch, with LED indicator (if required).

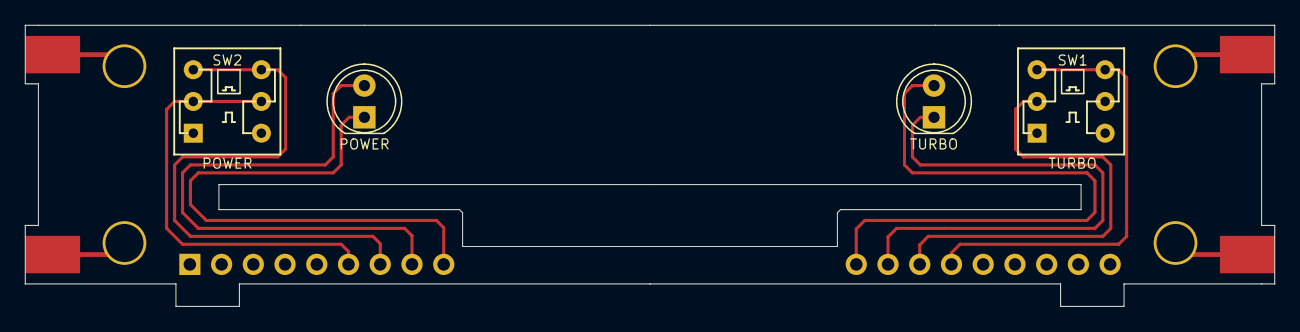
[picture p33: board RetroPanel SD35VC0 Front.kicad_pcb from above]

Board: 2 copper layers, 100.0 x 22.5 mm, 13 parts (1 on the bottom side), 9 nets.

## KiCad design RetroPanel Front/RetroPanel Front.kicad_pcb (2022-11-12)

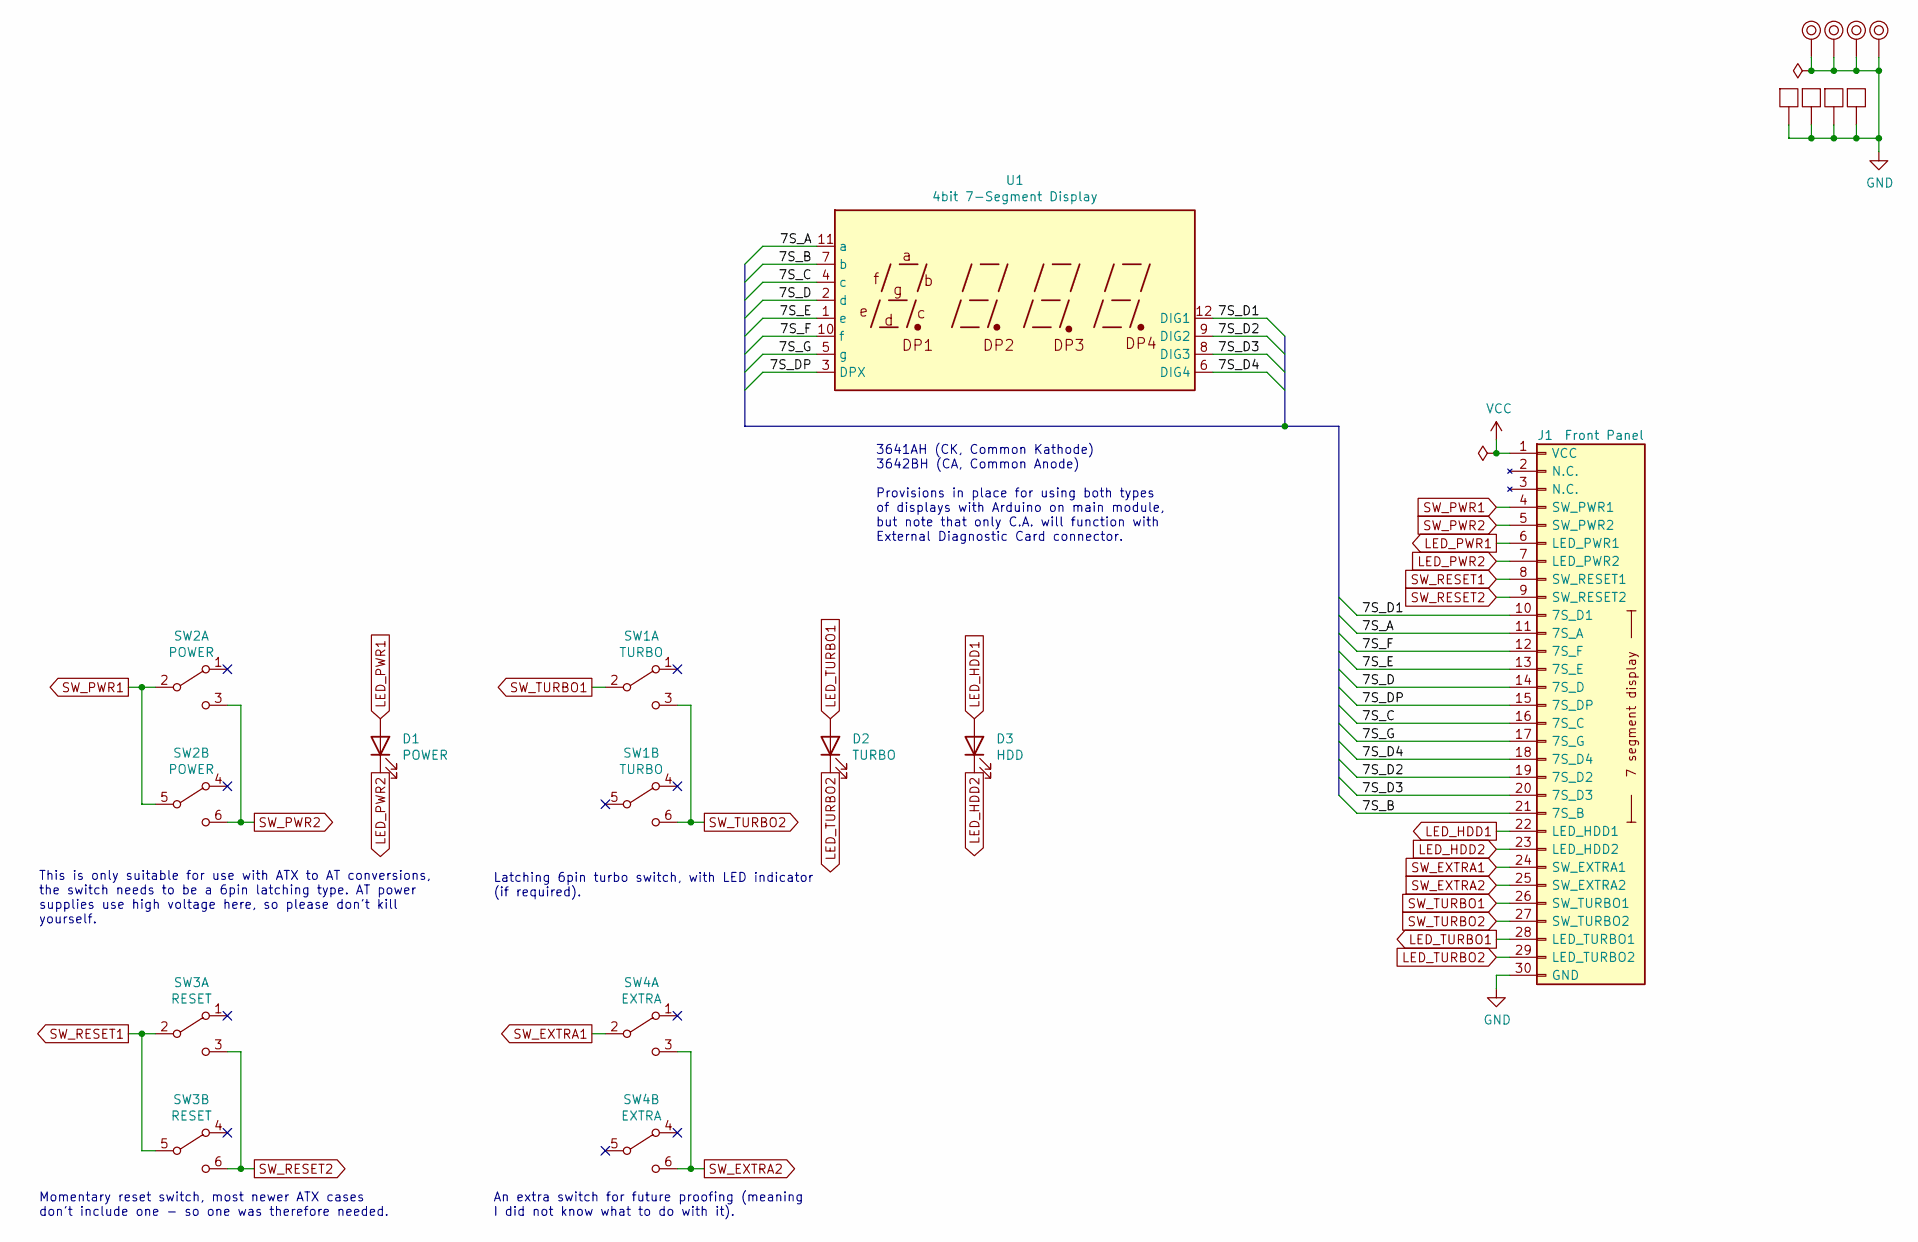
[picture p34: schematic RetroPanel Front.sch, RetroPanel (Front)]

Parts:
D1: POWER; LED_D5.0mm
D2: TURBO; LED_D5.0mm
D3: HDD; LED_D5.0mm
J1: Front Panel; PinHeader_1x30_P2.54mm_Horizontal
M1, M2, M3, M4: Mounting_Pin; M3_pin
M5, M7, M9, M10: Mounting_Pad; Pad_pin
SW1: TURBO; dpdt_switch_black
SW2: POWER; dpdt_switch_black
SW3: RESET; dpdt_switch_black
SW4: EXTRA; dpdt_switch_black
U1: 4bit 7-Segment Display; 3641AH

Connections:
/7S_A: J1.11 (7S_A), U1.11 (a)
/7S_B: J1.21 (7S_B), U1.7 (b)
/7S_C: J1.16 (7S_C), U1.4 (c)
/7S_D: J1.14 (7S_D), U1.2 (d)
/7S_D1: J1.10 (7S_D1), U1.12 (DIG1)
/7S_D2: J1.19 (7S_D2), U1.9 (DIG2)
/7S_D3: J1.20 (7S_D3), U1.8 (DIG3)
/7S_D4: J1.18 (7S_D4), U1.6 (DIG4)
/7S_DP: J1.15 (7S_DP), U1.3 (DPX)
/7S_E: J1.13 (7S_E), U1.1 (e)
/7S_F: J1.12 (7S_F), U1.10 (f)
/7S_G: J1.17 (7S_G), U1.5 (g)
GND: J1.30 (GND), M1.1, M2.1, M3.1, M4.1, M5.1, M7.1, M9.1, M10.1
LED_HDD1: D3.2 (A), J1.22 (LED_HDD1)
LED_HDD2: D3.1 (K), J1.23 (LED_HDD2)
LED_PWR1: D1.2 (A), J1.6 (LED_PWR1)
LED_PWR2: D1.1 (K), J1.7 (LED_PWR2)
LED_TURBO1: D2.2 (A), J1.28 (LED_TURBO1)
LED_TURBO2: D2.1 (K), J1.29 (LED_TURBO2)
SW_EXTRA1: J1.24 (SW_EXTRA1), SW4.2 (B)
SW_EXTRA2: J1.25 (SW_EXTRA2), SW4.3 (C), SW4.6 (C)
SW_PWR1: J1.4 (SW_PWR1), SW2.2 (B), SW2.5 (B)
SW_PWR2: J1.5 (SW_PWR2), SW2.3 (C), SW2.6 (C)
SW_RESET1: J1.8 (SW_RESET1), SW3.2 (B), SW3.5 (B)
SW_RESET2: J1.9 (SW_RESET2), SW3.3 (C), SW3.6 (C)
SW_TURBO1: J1.26 (SW_TURBO1), SW1.2 (B)
SW_TURBO2: J1.27 (SW_TURBO2), SW1.3 (C), SW1.6 (C)

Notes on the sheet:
This is only suitable for use with ATX to AT conversions, the switch needs to be a 6pin latching type. AT power supplies use high voltage here, so please don't kill yourself.
Latching 6pin turbo switch, with LED indicator (if required).
Momentary reset switch, most newer ATX cases don't include one - so one was therefore needed.
An extra switch for future proofing (meaning I did not know what to do with it).
3641AH (CK, Common Kathode) 3642BH (CA, Common Anode) Provisions in place for using both types of displays with Arduino on main module, but note that only C.A. will function with External Diagnostic Card connector.

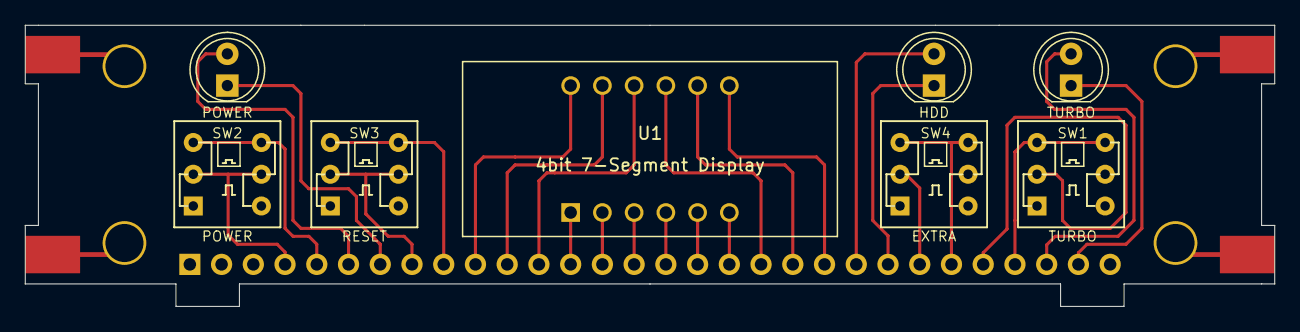
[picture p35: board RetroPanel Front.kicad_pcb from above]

Board: 2 copper layers, 100.0 x 22.5 mm, 17 parts (1 on the bottom side), 27 nets.

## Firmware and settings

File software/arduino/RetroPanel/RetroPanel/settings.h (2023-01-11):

#pragma once
#define BAUD_RATE_USB BAUD_RATE_115200
#define BAUD_RATE_RS232 BAUD_RATE_9600

#define DEFAULT_LED_PWR 64
#define DEFAULT_ANSI false
#define DEFAULT_TURBO false
#define DEFAULT_BOOT true
#define DEFAULT_CLOCK false
#define DEFAULT_CLOCK_FLASH true
#define DEFAULT_TEMPERATURE false
#define DEFAULT_RS232 true
#define DEFAULT_DISPLAY_TYPE DISPLAY_TYPE_CK

#define DEFAULT_LO_0 0
#define DEFAULT_LO_1 0
#define DEFAULT_LO_2 'l'
#define DEFAULT_LO_3 '0'
#define DEFAULT_HI_0 0
#define DEFAULT_HI_1 0
#define DEFAULT_HI_2 'h'
#define DEFAULT_HI_3 'i'
#define DEFAULT_BOOT_0 'b'
#define DEFAULT_BOOT_1 'o'
#define DEFAULT_BOOT_2 'o'
#define DEFAULT_BOOT_3 't'
#define DEFAULT_TEMP_0 0
#define DEFAULT_TEMP_1 0
#define DEFAULT_TEMP_2 '*'
#define DEFAULT_TEMP_3 'c'

#define ACTIVITY_THRESHOLD 10000
#define DISPLAY_THRESHOLD 0
#define SUPPORT_URL "https://github.com/tebl/RetroPanel"

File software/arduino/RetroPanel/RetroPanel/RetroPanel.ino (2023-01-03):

#include <Arduino.h>
#include "constants.h"
#include "settings.h"
#include "commands.h"
#include "storage.h"
#include "hex_display.h"
#include "serial_console.h"
#include "clock.h"
#include "temperature.h"

bool ansi_enabled = DEFAULT_ANSI;
bool turbo_enabled = DEFAULT_TURBO;
bool boot_enabled = DEFAULT_BOOT;
bool clock_enabled = DEFAULT_CLOCK;
bool clock_blinking = DEFAULT_CLOCK_FLASH;
bool rs232_enabled = DEFAULT_RS232;
bool temperature_enabled = DEFAULT_TEMPERATURE;
uint8_t display_type = DEFAULT_DISPLAY_TYPE;

unsigned long last_activity = 0;
char str_lo[4] = {DEFAULT_LO_0, DEFAULT_LO_1, DEFAULT_LO_2, DEFAULT_LO_3};
char str_hi[4] = {DEFAULT_HI_0, DEFAULT_HI_1, DEFAULT_HI_2, DEFAULT_HI_3};
char str_boot[4] = {DEFAULT_BOOT_0, DEFAULT_BOOT_1, DEFAULT_BOOT_2, DEFAULT_BOOT_3};
char str_clock[6] = {0,0,0,0,0,0};
char str_temperature[4] = {DEFAULT_TEMP_0, DEFAULT_TEMP_1, DEFAULT_TEMP_2, DEFAULT_TEMP_3};

void setup() {
  process_serial_init();
  pinMode(PIN_PWR, OUTPUT);
  analogWrite(PIN_PWR, DEFAULT_LED_PWR);
  pinMode(PIN_TURBO, INPUT);

  print_welcome();
  restore_settings();
  hex_display_init();

  if (boot_enabled) {
    hex_display_set(str_boot);
    last_activity = millis();
  }

  if (clock_enabled) {
    clock_init();
  }

  if (temperature_enabled) {
    temperature_init();
  }
}

int last_turbo = -1;
int current_turbo = -1;
void process_turbo() {
  // Give other functions a chance to have something displayed
  if (last_activity == 0 || ((millis() - last_activity) > ACTIVITY_THRESHOLD)) {
    if (turbo_enabled) {
      current_turbo = digitalRead(PIN_TURBO);
      if (last_turbo != current_turbo) {
        if (current_turbo == LOW) {
          hex_display_set(str_lo);
        } else {
          hex_display_set(str_hi);
        }
        last_turbo = current_turbo;
      }
    }
  }
}

void process_clock() {
  // Give other functions a chance to have something displayed
  if (last_activity == 0 || ((millis() - last_activity) > ACTIVITY_THRESHOLD)) {
    if (clock_enabled) {
      clock_update();
    }
  }
}

void process_temperature() {
  // Give other functions a chance to have something displayed
  if (last_activity == 0 || ((millis() - last_activity) > ACTIVITY_THRESHOLD)) {
    if (temperature_enabled) {
      temperature_update();
    }
  }
}

void loop() {
  process_serial();
  process_turbo();
  process_clock();
  process_temperature();
  hex_display_scan();
}

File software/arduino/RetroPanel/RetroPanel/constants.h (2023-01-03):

#pragma once
#define APP_TITLE "RetroPanel"
#define APP_VERSION "0.1"

#define BAUD_RATE_115200 115200
#define BAUD_RATE_38400 38400
#define BAUD_RATE_19200 19200
#define BAUD_RATE_9600 9600
#define BAUD_RATE_4800 4800

#define TERMINAL_COLS 80
#define PIN_SDA 2
#define PIN_SCL 3
#define PIN_PWR 9
#define PIN_TURBO 21

#define PIN_7S_A 20
#define PIN_7S_B 19
#define PIN_7S_C 18
#define PIN_7S_D 15
#define PIN_7S_E 14
#define PIN_7S_F 16
#define PIN_7S_G 10
#define PIN_7S_DP 8
#define PIN_7S_DIGIT_1 4
#define PIN_7S_DIGIT_2 5
#define PIN_7S_DIGIT_3 6
#define PIN_7S_DIGIT_4 7

#define DISPLAY_TYPE_CK 0
#define DISPLAY_TYPE_CA 1

const char STR_VALUE[] PROGMEM = "Value";
const char STR_DONE[] PROGMEM  = "done!";
const char STR_ON[] PROGMEM = "ON";
const char STR_OFF[] PROGMEM = "OFF";
const char STR_ERROR_ARG[] PROGMEM = "argument format";

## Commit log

2022-10-25 Front panel
    [RetroPanel Front.kicad_pcb, RetroPanel Front.sch]
2022-10-25 Layout first draft
    [RetroPanel Front.kicad_pcb, RetroPanel Front.sch]
2022-10-26 Add extra switch and tweak size
    [RetroPanel Front.kicad_pcb, RetroPanel Front.sch]
2022-10-26 Add mounting pads
    [RetroPanel Front.kicad_pcb, RetroPanel Front.sch]
2022-10-26 Add side panel
    [RetroPanel Side.kicad_pcb, RetroPanel Side.sch]
2022-10-26 Match grid
    [RetroPanel Front.kicad_pcb]
2022-10-27 Rough layout of module
    [RetroPanel Front.kicad_pcb, RetroPanel Front.sch, RetroPanel Module.kicad_pcb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]
2022-10-28 First schematic draft
    [RetroPanel Module.kicad_pcb, RetroPanel Module.sch]
2022-10-30 First layout draft done
    [RetroPanel Module.kicad_pcb, RetroPanel Module.sch, rs232.sch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]
2022-10-30 Small tweaks
    [RetroPanel Module.kicad_pcb]
2022-10-30 Faceplate FP1 and HDD LED
    [RetroPanel FP1.kicad_pcb, RetroPanel FP1.sch, RetroPanel Front.kicad_pcb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]
2022-10-31 FP1 icons
    [RetroPanel FP1.kicad_pcb]
2022-10-31 Export files
    [RetroPanel FP1.kicad_pcb, RetroPanel Front.kicad_pcb, RetroPanel Module.kicad_pcb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]
2022-11-07 Moved power diode
    [RetroPanel Module.kicad_pcb, RetroPanel Module.sch, smart_switch.sch]
2022-11-07 Bumped version
    [RetroPanel Front.kicad_pcb]
2022-11-09 Tweak display cutout
    [RetroPanel FP1.kicad_pcb]
2022-11-09 Can use both types of displays
    [RetroPanel Front.kicad_pcb, RetroPanel Front.sch]
2022-11-09 Better description for CA display usage
    [RetroPanel Module.kicad_pcb, RetroPanel Module.sch, smart_switch.sch]
2022-11-11 Tweaked resistor value to work better 7S CA
    [RetroPanel Module.kicad_pcb, RetroPanel Module.sch]
2022-11-12 Adjustable mounting with huge pads
    [RetroPanel Module.kicad_pcb, RetroPanel Module.sch, RetroPanel Side.kicad_pcb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]
2022-11-12 Optional standby power LED
    [RetroPanel Module.kicad_pcb, smart_switch.sch]
2022-11-12 Fixed RS-232 connector and export files for second prototype
    [RetroPanel FP1.kicad_pcb, RetroPanel FP1.sch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]
2022-11-16 Add external pullup for Serial1 RX
    [RetroPanel Module.kicad_pcb, RetroPanel Module.sch]
2022-12-01 Add mounting spot for DS3231 directly
    [RetroPanel Module.kicad_pcb, RetroPanel Module.sch]
2023-01-03 Adjust cutout to move unit forward
    [RetroPanel Module.kicad_pcb, RetroPanel Module.sch, RetroPanel Side.kicad_pcb]
2023-01-11 Silkscreen tweaks
    [RetroPanel Module.kicad_pcb]
2023-01-23 Faceplate tweaks (non-visible)
    [RetroPanel FP1.kicad_pcb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]
2023-01-28 SD35VC0 sketched out
    [RetroPanel SD35VC0.kicad_pcb, RetroPanel SD35VC0.sch, rs232.sch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]
2023-01-29 SD35VC0 Front sketched out
    [RetroPanel SD35VC0 Front.kicad_pcb, RetroPanel SD35VC0 Front.sch, RetroPanel SD35VC0.kicad_pcb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]
2023-01-31 Changed SW_PWR to pads for cable as it probably should be
    [RetroPanel Module.kicad_pcb, RetroPanel SD35VC0.kicad_pcb, RetroPanel SD35VC0.sch]
2023-02-06 Add some links to assembly video
2023-02-06 Shorten lower lip
    [RetroPanel FP1.kicad_pcb, RetroPanel FP2.kicad_pcb]
2023-02-06 Removed unused files
    [rs232.sch, smart_switch.sch]
2023-02-07 Change schematic text
    [SD35VC0 FP1.sch]
2023-02-23 Adjust faceplate cutouts
    [SD35VC0 FP1.kicad_pcb]
